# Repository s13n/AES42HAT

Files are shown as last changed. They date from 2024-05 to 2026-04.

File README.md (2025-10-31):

# AES42HAT

The AES42HAT is a Raspberry Pi compatible HAT with up to 4 channels of
AES3/AES42 interface. At present it is a work in progress.

AES3 is the stereo digital audio interface for professional applications, which
is compatible to some extent with SPDIF as used on consumer gear.

AES42 is building on AES3 to provide power and control for digital microphones.

Depending on what is fitted on the board, AES42HAT supports up to 4 stereo
channels of input/output, with or without SRC on input, and with or without
external synchronization.

Raspberry Pi models up to the Raspberry Pi 4B, and various clones, support only
one stereo channel in/out. The Raspberry Pi 5 supports the full set of 4 stereo
channels. The BeagleY-AI also supports 4 stereo channels in/out.

The 4 inputs and outputs are available on a header that supports the "Tascam
pinout" (or AES59 pinout) for a 25-pin SubD connector for multichannel digital
input/output. A standard IDC cable adapter between the header and the SubD
connector is needed.

## Build variants

The design supports different variants, depending on which parts are fitted on
the board. This allows a tradeoff between cost and feature set, depending on
user's needs.

See the schematics for the function blocks that can be omitted if desired. The
bare minimum consists of the parts that are shown outside of an optional block.

The Raspberry Pi uses the ID EEPROM to determine the build variant.

### Minimum build -- AES42HAT lite

The minimum build uses a DIX4192 for U10, and omits everything in the optional
blocks. It provides a stereo input/output in AES3 format, without SRC. It is
compatible with most Raspberry Pi models and some clones, provided they feature
a PCM interface on the standard pins, and a finely adjustable clock source on
GCLK0. It offers minimal cost for stereo applications that don't need AES42
support or SRC.

The lack of SRC means that there are only two sensible clocking options:

- The Raspberry Pi supplies the clock, and both input and output use it. This
  can be useful when an external device is connected, that synchronizes to the
  signal it receives from the AES42HAT.
- The output uses the clock derived from the received signal. This is useful
  when the external device is treated as the clock source, and the Raspberry is
  following it.

In both cases input and output use the same clock, i.e. they are synchronous to
each other.

The lack of a clock synthesizer means that the HAT is dependent on the Raspberry
Pi for a clock source. The original Raspberry Pi contains finely tunable PLLs
which can output a clock signal on GCLK0 that acts as a clock master. If a clone
doesn't support this, it won't work.

The lack of a control processor means that the DIX4192 is configured and
controlled directly by the Raspberry Pi through its SPI0 interface.

### Full-featured stereo interface -- AES42HAT stereo

This is the AES42HAT lite with an SRC4392 for U10, plus the clock synthesizer.

This adds the capability of using SRC on input, so the input clock can be
independent from the output clock. The presence of a clock synthesizer
eliminates the dependency on the Raspberry Pi clock generator, and adds a
separate wordclock input and output to support synchronization.

The clock syntheziser may also be slaved to a 10 MHz reference input as commonly
used in measurement equipment and frequency references. This can be used for
measurement purposes, or for creating audio clocks from GPS receivers and highly
stable oscillators.

The clock synthesizer is controlled by the Raspberry Pi through its I2C bus.

### Full-featured 8-channel interface -- AES42HAT octal

This adds 3 more stereo channels to the AES42HAT stereo to form a bidirectional
8-channel interface. SRC is supported on all channels by virtue of 3 more
SRC4392 chips, so that each input can run on its own clock, while all outputs
share a common clock generated by the local clock synthesizer.

The addition of more channels also requires the local control processor. The
SPI0 interface on the Raspberry Pi is no longer needed. All control is done via
the I2C bus, with the control processor managing the multiple channels.

Any of the input channels can be used as a synchronization source, instead of
the separate wordclock input.

The usage of a Raspberry 5 or a BeagleY-AI is needed to handle all the audio
channels.

### Full-featured 8-channel interface with AES42 support -- AES42HAT microphone

This adds AES42 compatible phantom power and remote control capability to all 4
stereo input channels of the AES42HAT octal. All synchronization modes of AES42
are supported, and the microphones can be remote controlled, independently for
each of the 4 inputs.

This requires a power supply that can deliver the necessary current for powering
the microphones in addition to the Raspberry Pi with the HAT. It is recommended
to use a 25W power supply capable of delivering 5A@5V to the Raspberry Pi 5.
Appropriate cooling should be provided.

The local control processor takes care of the AES42 specifics, and the Raspberry
Pi controls and monitors it via I2C.

If the goal is to merely power and control AES42 microphones, whose audio signal
is made available on the AES3 outputs, with no intent to process the audio with
the Raspberry Pi, then a cheaper/smaller Raspberry Pi can be used, for example a
Pi Zero 2. When intending to process the audio with the Raspberry Pi, use a
Raspberry Pi 5 or a BeagleY-AI.

## Function blocks

### Power Supply and Reset

The AES42HAT is powered through the HAT connector's 5V supply. Only the board ID
EEPROM (U3) is powered from the 3.3V supply on the HAT connector (J1). A dual
DC/DC converter (U4) generates local 3.3V and 1.8V rails for most of the
electronics on the board. The DC/DC converter is enabled by the 3.3V supply from
the HAT connector, so when the Raspberry Pi is powered down, the AES42HAT is
also powered down, even though the 5V rail may remain on.

The Raspberry Pi is responsible for lifting the RESET line after powerup,
otherwise the AES42HAT will remain in reset due to R5 pulling down the RESET
line. The ID EEPROM can be accessed regardless if the board is in reset or not.

### Local Control Processor (optional)

The 8-channel variants of the AES42HAT have a local control processor (U1)
fitted, which configures and controls the receivers and transmitters, and
handles the phantom powering, the remote control and the synchronization of the
AES42 interfaces.

The Raspberry Pi accesses the control processor primarily through I2C, using
pins 3&5 on the HAT connector. The Raspberry Pi controls this interface, and the
AES42HAT is the target. The communication protocol is TBD.

There is also a UART connection between the Raspberry Pi and the control
processor on pins 8&10. This connection can be used for updating the firmware of
the control processor from the Raspberry Pi. It may also be used during normal
operation for a console-like communication interface. The details are TBD.

There is an additional signal on Pin 26 of the HAT connector (REQ/ISP), which
serves two purposes:

- Upon release of RESET, the signal determines the boot mode of the control
  processor. When high, the control processor boots normally and executes its
  stored firmware. When low, it boots into a bootloader that can be used to
  update its firmware through the UART interface. Hence, to initiate firmware
  update, the Raspberry PI has to pull this signal low while releasing RESET.
- During normal operation, the signal is used as a service request signal from
  the AES42HAT to the Raspberry Pi. It is up to the Raspberry Pi to poll the
  signal, or arrange for an interrupt to be generated whenever the signal goes
  low. The control processor holds the interrupt active until the Raspberry Pi
  clears it through the I2C interface. The details are TBD.

When the control processor is fitted, the Raspberry Pi's own SPI interface on
HAT connector pins 19,21,23&24 is not used and must be disabled.

### Clock Synthesizer (optional)

The clock synthesizer supports generating arbitrary audio clock frequencies, and
to reference them to an external clock source. This provides considerable
flexibility in setting up the clocking structure of a system. The following
features are supported:

- Support for any sampling rate the Receivers/Transmitters are capable of (20 ..
  216 kHz). All transmitters use the same rate, and are synchronous to each
  other.
- Sampling rate can be finely tuned by software.
- An external 10 MHz reference can be connected to support synchronization from
  highly stable frequency sources (GPS receivers, OXCOs, Rubidium sources, ...).
  This can also help measurement applications. If no external reference is used,
  an internal 10 MHz crystal is used. The reference signal can be made available
  internally as the ACLK signal.
- Any one of the AES3 input signals can be used as the synchronization source.
- An external TTL wordclock signal can be connected to serve as a
  synchronization source.
- A TTL wordclock output is available.

All those features are controlled from software. The clock synthesizer is
connected to the I2C bus (HAT connector pins 3&5) that is controlled by the
Raspberry Pi. It produces two output clocks:

- The MCLK signal is the audio master clock from which the transmitters derive
  their output signal. The audio interface of the Raspberry Pi (PCM) is also
  driven from this clock, and operated in slave mode. The MCLK signal connects
  to pin 7 of the HAT interface. This allows the Raspberry Pi to supply the
  audio master clock instead of the clock synthesizer. The clock synthesizer's
  output must be switched off in this case (if it is fitted).
- The ACLK signal is typically driven by the 10 MHz reference clock signal. It
  can be used in the AES3 receivers as a reference signal for measuring incoming
  sampling rates.

The MCLK frequency should be between 10 and 25 MHz. For a single-speed sampling
rate up to a nominal 48 kHz, MCLK should be 512 * Fs. For a double-speed rate up
to 96 kHz it should be 256 * Fs. For a quad-speed rate up to 192 kHz it should
be 128 * Fs. The dividers in U10 must be set up to divide this down to the right
bit clock and word clock.

The clock synthesizer has a separate synchronization input that is driven by the
RCLK signal. Its use is optional, determined by software.

- If RCLK is not used, the 10 MHz signal is used as the reference, from which
  MCLK is derived directly using a fractional PLL.
- If RCLK is used, MCLK is derived from it by steering the fractional multiplier
  of the PLL to track the frequency of RCLK. This also reduces the jitter that
  may be present on RCLK. A wide frequency range on RCLK is supported (50 Hz ..
  30 MHz). Skipped pulses on RCLK can also be supported.

The RCLK signal can be fed from different sources:

- In the default case, it is fed from the external wordclock input. This is a
  TTL level signal that need not work at the wordclock frequency. It may be used
  to synchronize to a wide range of external frequency sources. The Raspberry Pi
  must enable it by driving the WIEN signal low.
- It can alternatively be fed from one of the receivers, using their RXCKO
  output. This output can be enabled to provide a clock signal derived from the
  incoming AES3 signal. It allows an incoming audio signal to be used as the
  synchronization source for the clock synthesizer. On 8-channel variants of
  AES42HAT, only one of four receiver chips can have this output enabled, or
  they will interfere with each other, potentially leading to damage. The output
  is disabled by default. Before enabling one of them, the Raspberry Pi must
  disable the external wordclock signal by driving the WIEN signal high.
- The Raspberry Pi can drive the RCLK signal using its GCLK2/GPIO6 signal on pin
  31 of the HAT connector. Both the wordclock input and the receiver RXCKO
  outputs must be disabled before the Raspberry Pi can activate this signal.

The clock syntheizer can be a CS2000 (obsolete), a CS2500 or a THAT7200. Its I²C
address is 0x4F (0x9E for write, 0x9F for read).

### AES Receivers/Transmitters

Decoding and encoding of the AES3 signal is done by U10 (on 8-channel variants
also U20, U30 and U40). There are three pin-compatible chips that can be fitted
alternatively:

- The **DIX4192** is a receiver and transmitter for one AES3 signal, including
  the balanced driver and receiver necessary for the physical interface.
- The **SRC4392** includes a sampling rate converter (SRC) that can be used with
  either the receiver or the transmitter, but is most useful with the receiver.
  Its other functions are the same as with the DIX4192, and the software
  interface is compatible.
- The **SRC4382** saves some cost by including a less accurate SRC that offers
  worse signal to noise. While this chip can be used, the cost savings are
  usually not worth it, and the AES42HAT will only use it upon special request.

Whichever chip is fitted, most of the functionality is the same. It has an
extensive register set for controlling the details of operation, which is
accessed through an SPI compatible interface.

When the local control processor is fitted, it is in control of the SPI
interface used to configure and control the receivers/transmitters.

The chips have flexible internal signal routing and clocking, which is set up
through the SPI control interface. Routing and clocking is set up as follows:

- U10 is the clock master on the PCM interface to the Raspberry Pi. Audio port A
  is configured in master mode and produces the BCLK and LR clock signals, with
  MCLK as the clock source. The BLS pin is configured as output.
- When fitted, U20, U30 & U40 operate their audio ports A&B in slave mode, so
  the BCKA, BCKB, LRCKA and LRCKB pins are inputs. The BLS pin is also
  configured as input.
- The transmitters within U10, U20, U30 and U40 are typically configured to be
  sourced from audio port A. The transmitter thereby sends an audio signal
  provided by the Raspberry Pi.
- Alternatively, the received input signal can be passed through to the output
  directly, using the pin multiplexers, bypassing the DIR and DIT blocks.
- The SRC is used with the receiver to convert the sampling rate of the received
  signal to the clock used on port A. If the input signal is known to be
  synchronous with this clock, the SRC can be omitted from the signal path.
- The ACLK signal (nominally 10 MHz) is available on the RXCKI signal, and can
  be used as a reference for the SRC to estimate the ratio. It can also be used
  as a reference clock for the DIR block. When the clock synthesizer is not
  fitted, the ACLK signal is not available, and the MCLK signal must be used as
  a reference.

Each receiver/transmitter has 4 GPO pins that have programmable functionality.
On the AES42HAT, they are used as follows:

- **GPO1** is used to enable phantom power for the AES42 input. If the AES42
  circuit is not fitted, the signal is unused. The output defaults to low after
  reset, thereby turning phantom power off.
- **GPO2** is used to select between two synchronization modes of AES42. This is
  only relevant when phantom power is switched on. A low signal selects mode 2,
  which is the default after reset.
- **GPO3** is connected to the control processor, and is intended to carry the
  reconstructed wordclock signal from the receiver ("Receiver Internal Sync
  Clock"). If the control processor is not fitted, the signal is unused.
- **GPO4** is connected to the control processor, and is intended to carry the
  received U-bit ("Receiver User Data Bit"), giving the control processor an
  alternate way to process the incoming user bit. If the control processor is
  not fitted, the signal is unused.

If the intended functionality of GPO3&4 is not required, other signals may be
chosen to be fed to the control processor.

Each receiver/transmitter can generate an interrupt signal. The interrupt signal
is handled by the control processor, if it is fitted. Otherwise the interrupt
from U10 is fed to the Raspberry Pi on HAT connector pin 26.

### AES42 Phantom Supply and Remote Control

AES42 defines a way of powering a connected microphone using a 10 V phantom
power scheme. Additionally, remote control signals can be sent to the microphone
by modulating them on top of the phantom power. The "AES42HAT microphone", the
fully featured variant, supports both.

Phantom power is generated by a DC/DC converter (U51, U61, U71, U81). Each input
can be powered separately, controlled by GPO1 of the respective
receiver/transmitter. The DC/DC converter works from the +5V rail, and each
circuit potentially draws up to 600mA from this rail, depending on the load
represented by the microphone that is connected. The power supply used must be
able to deliver this amount of current.

The control processor can monitor the phantom voltage through signals PVx, so it
can diagnose short circuits or overload.

Remote control using AES42 Mode 2 is handled by raising the phantom voltage for
each pulse generated. This is achieved by temporarily switching the DC/DC
converter to output 12 V instead of 10 V. Edge speed is shaped by an additional
driver (U52, U62, U72, U82).

Mode 3 is supported by a different circuit built from a signal transformer (L50,
L60, L70, L80) driven by a bandpass amplifier (U53, U63, U73, U83). It is based
on a clock signal WCLK generated by the control processor.

For both modes, the modulating signal (MODx) is generated by the control
processor. Switches (U50, U60, U70, U80) are used to select between the two
modes, depending on signals M3x sourced by GPO2 of the receiver/transmitter.

An LED shows the presence of phantom power on each channel. Its brightness is
modulated by the remote control pulses.

### Dependencies Between Optional Function Blocks

The control processor must be fitted if any of U20, U30 or U40 are fitted. It
must also be fitted when the AES42 circuitry is fitted.

The clock synthesizer is controlled by the Raspberry Pi and can be fitted
without the control processor. The clock synthesizer is independent from any
other function block and can be fitted or omitted, regardless of which other
options are fitted. However, if not fitted, the Raspberry Pi must supply the
audio master clock (GCLK0).

## Support for Raspberry Pi Variants and Clones

The AES42HAT is fully compatible with the Raspberry Pi 5, including support for
up to 8 channels of audio input and output.

Previous models of the Raspberry Pi up to the 4B only support stereo audio. The
8-channel variants of AES42HAT can therefore not be fully supported, i.e. the
audio signals of the additional channels can't be accessed by the Raspberry Pi.
The additional channels can be controlled and configured, however, so it is
possible to support use cases where the audio signals need not be touched by the
Raspberry Pi (for example using pass-through from input to output, without or
with SRC).

Raspberry Pi clones may or may not support the PCM interface, so it is up to the
user to check compatibility. In many cases only stereo is supported, if at all.

### BeagleY-AI

The BeagleY-AI is a clone that can support all 8 channels, albeit with some
special arrangements. The pin assignment for the PCM interface is only partly
compatible with the Raspberry Pi 5, and AES42HAT contains some additional wiring
to make up for the difference.

With the BeagleY-AI, the McASP0 is used for all the input signals with up to 8
channels. The output channels are generated by McASP1 and McASP2 in SPDIF
transmit mode. The latter is necessary because of limitations of clock signal
connectivity. The input multiplexers in the receivers/transmitters are used to
route the output signals directly to the balanced line driver, bypassing the DIT
block. To deal with wiring differences for input channels, audio port B is used
on U30 and U40.

### ESP32-P4 Function Evaluation Board

The Espressif ESP32-P4 is a microcontroller with a dual-core RISC-V CPU and a
rich set of peripherals, including I2S and 100 MBit/s Ethernet. It appears to
have some potential for a very low cost platform for low-end networked audio
devices, below the price point of a Linux-based solution. Its evaluation board
has a set of GPIO signals routed to a Raspberry Pi HAT connector. This opens the
possibility to use the AES42HAT as an audio interface.

The ESP32-P4 has 3 I2S function blocks that can be freely assigned to GPIO pins,
and it includes a PLL dedicated for audio. It therefore should be able to work
with the AES42HAT directly, with no need for a wiring change. At the time of
writing, the information available for the ESP32-P4 is sparse, hence the
suitability is somewhat unclear at this point, but it certainly looks promising.

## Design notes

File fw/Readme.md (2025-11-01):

# AES42HAT firmware

The AES42HAT uses the LPC865M201 as a local control processor (U1). The firmware
for this MCU is contained in this folder here.

The control processor has a number of responsibilities on the AES42HAT:

- Initialize the board
- Collect the user bit and control/status bit data from the AES Receivers (U10,
  U20, U30, U40) via SPI, and present them to the Host processor via I2C.
- Receive the user bit and control/status bit data for the AES Transmitters (U10,
  U20, U30, U40) from the host via I2C, and set them via SPI.
- Measure the relative clock phases between the AES Transmitters, and each of
  the AES Receivers, to support AES42 Mode 2 synchronization.
- Manage phantom powering and remote control of an AES42 compatible source.

The details are described in the succeeding chapters here.

## General control processor operation

The control processor is mainly used for configuring the transceiver chips, and
for handling the channel status and user bits of the AES3 / AES42 signals. This
is important since AES42 makes full use of those bits, and it greatly helps a
host processor when this side-band information handling is offloaded into a
specialized processor.

### Handling of C and U bits

The transceiver chips U10, U20, U30 and U40 have a double-buffered memory for
the entire C and U bit information for both receiver and transmitter side. The
buffers can be accessed through the SPI control port. The speed of the SPI port
is sufficient for keeping up with the data rate of 4 transceivers operating in
parallel in both directions (using the I2C bus mode instead wouldn't provide
enough speed). The control processor is intended to read the incoming data on
all channels once for every block of 192 samples. Optionally, it should also be
able to write the outgoing data for all 4 channels for every block of 192
samples, too.

The transmitters are all synchronized to the same clock, therefore the data
blocks can be written in common. The trigger (interrupt) for writing new blocks
comes from the BLS signal. For each trigger, 192 * 8 * 2 bits = 3072 bits = 384
bytes must be written if all channels are to be covered. This is because there
are separate blocks of 192 bits for each of 8 subchannels' C and U bits.

The receivers are clocked individually, and each may operate at a different
frequency. Therefore the data transfer is triggered separately for each. With
each trigger, 768 bits = 96 bytes must be read. The trigger comes from the INT
signal of the respective transceiver, which must be programmed to fire once per
received block.

This means that 5 independent trigger sources compete for SPI bandwidth,
requiring arbitration. The worst case occurs at the highest sampling rates of
~200 kHz for both receivers and transmitters, which leads to a total net data
rate of 800 kByte/s, or 6.4 MBit/s. In practice, the clock rate of the SPI port
will therefore need to be 10 .. 30 MBit/s, which is within the capability of
both the control processor and the transceiver chips.

The SPI interface in the control processor supports DMA, which is useful in this
scenario, to relieve the CPU of handling the actual data transfer.

Note that all 5 trigger signals (BLS, INTA, INTB, INTC, INTD) are connected to
support time stamping with FTM0. This permits phase measurements (see below), as
well as frequency measurements. FTM0 has 6 channels, of which 5 are used for
this purpose.

### Transceiver configuration

The control processor configures the transceiver chips according to the desired
operation mode. This is determined by the host processor, which uses the I2C
interface to set the operation mode by writing control data to the control
processor. The control processor then configures the transceivers accordingly
via SPI0.

### Other functions

The control processor monitors the phantom voltage of all 4 channels using its
ADC (inputs ADC_0 .. ADC_3). It can report the values to the host via the I2C
interface. A significant deviation from the nominal values of 10V or 12V
indicates a hardware problem.

Host communication, microphone synchronization and remote control are described
below in their respective chapters.

### Control processor clock setup

Most of the functions of the control processor don't need to be synchronized
with the audio clock. An internal free running oscillator can clock the chip at
60 MHz, and generate most of the required clocks, including the CPU clock.

For additional flexibility, both MCLK and ACLK signals are routed to the control
processor where they can be used for further clocking related tasks. Either one
or the other can be used to supply the internal `external_clk` signal, which can
serve as the reference for a PLL to generate arbitrary frequencies.

## Mode 2 clock synchronization

When AES42 was developed, one of the problems to solve was how to synchronize
the microphone to a common wordclock, given that the audio signal runs in the
"wrong" direction from the microphone to the controller, where the synchronizing
wordclock needs to go the other way. The solution devised was to establish a
distributed PLL using the remote control facility, which allows low-speed
control signals to be sent by the controller to the microphone via a modulation
scheme of the phantom power. A periodic control word generated by the controller
transmits the phase error to the microphone, where it tunes the clock generator
to produce the correct frequency.

The modulation scheme requires the phantom power of nominally 10 V to be raised
to 12 V in pulses that contain the information. On the AES42HAT, this is done by
switching a boost switchmode regulator between 10 and 12 V, and shaping the
transitions with a pulse driver. This avoids the power dissipation losses of a
linear regulator that is commonly used for this function.

### Controlling pulse timing

The pulse timing is controlled by the control processor, taking advantage of its
FTM1 timer module in conjunction with firmware. In mode 2, the pulses needn't be
synchronous with the wordclock, so the only requirement is to produce the
correct pulse widths according to the AES42 specification. This allows the TIM1
to be clocked internally. FTM1 has 4 channels which are used to control the 4
AES42 channels, so communication can proceed on all channels simultaneously.
Each of the timer channels controls one MODx signal.

The basic idea is to program the TIM1 such that its counter produces one TOF
event per bit that is sent as the remote control signal. Each bit is represented
by a signal that is initially low, and changes to high during the bit period.
For a 0 bit the transition to high happens late during the bit period, while for
a 1 bit it happens early.  This can be generated by using the PWM capability of
the TIM1. During the bit period the counter counts up from its initial value in
CNTIN to its final value in MOD, thereby defining the time for an entire bit.
Somewhere in between, an output transition happens as a consequence of a compare
event. This is what is described as "Edge-Aligned PWM" in the reference manual
of the control processor.

It is possible to trigger a DMA channel on the reloading of the counter (see bit
INITTRIGEN), and have it rewrite the compare registers. This can be used to
reduce the interrupt load by precomputing a list of transition points and
placing it in memory. Alternatively, an interrupt can be generated and the
interrupt service routine takes care of setting the compare registers once for
each bit period.

Firmware bears the responsibility to convert the data to be sent into the
appropriate timing values to use by the TIM1 channel for each bit.

### Phase detection

The control processor implements the phase detection part of the distributed
PLL. It consists of comparing the phase of the incoming AES42 signal with the
local wordclock signal. One phase measurement is needed for each time a control
word is sent to the microphone, which is nominally 6 times per second. Therefore
it is acceptable, and even advantageous, to use the block start signal instead
of the wordclock, to take a phase measurement. This allows aligning the block
start in addition to the wordclock.

The action of the PLL is supposed to minimize the phase error by steering the
clock generator in the microphone. To achieve this, the measured phase error is
filtered and converted into a 13-bit data word which is sent to the microphone 6
times per second. The microphone uses the data word to set the frequency of the
clock generator within a narrow band centered around the nominal frequency.
Traditionally this was done by having a D/A converter control a voltage
controlled crystal oscillator. Other arrangements that produce a similar effect
are also possible, however.

The phase detection is done with the help of TIM0 in capture mode. Its channel 3
captures the edges of the BLS signal, which is the block start signal derived
from the local wordclock. This serves as the reference against which the phase
of the incoming signal from the microphones is measured. The 4 AES42 inputs use
channels 0, 1, 4 and 5 of TIM0, so their phases can be measured simultaneously.
The phase difference is the capture value of the microphone channel minus the
capture value of the reference channel.

The counter of TIM0 is free running, and clocked internally from a clock source
that is unrelated to the audio clocks. This effectively dithers the measurement
results and avoids systematic quantization errors. Additionally, since block
starts are much more frequent than control word transmissions, measurements can
be averaged or smoothed to increase resolution even further.

Implementing phase detection in this way depends on each transceiver chip (U10,
U20, U30, U40) generating an interrupt signal when there is a block start of the
incoming audio signal. This also signals that a complete block of channel status
and user bits has been received and should be fetched using the SPI interface,
so the interrupt signal should not merely cause a capture in TIM0, but the
interrupt service routine should also schedule the data transfer using the SPI
interface.

### Fast mode

The AES42 standard supports two different communication speeds for the remote
control signal, standard mode and fast mode, with support for the latter being
optional for both the microphone and the controller. The implementation
described above for the AES42HAT can support either, but all four channels must
operate in the same mode, because of the usage of a common timer for generating
the timing.

In practice, fast mode would therefore be useable only if all connected
microphones support it. It shouldn't be selected otherwise.

## Mode 3 clock synchronization

As mode 2 synchronization has some disadvantages, Schoeps devised an additional
mode 3 as a different way of remote controlling and synchronizing the
microphone. In mode 3, the synchronization doesn't use the remote control
facility, it is the other way around. The remote control commands get sent
using the synchronization signal as a carrier.

Synchronization is achieved by modulating a low level sinewave onto the phantom
power, with the wordclock frequency as the carrier frequency. On the microphone
side, a narrow band circuit can retrieve this carrier despite its low level. The
advantage is that the chance of interference with the audio signal in the
microphone is greatly reduced, as is the potential radiation from the cable.
Furthermore, it is not necessary to support remote control just for
synchronization. If synchronization is all that's needed, it suffices to just
send the carrier.

The controller needs to be able to generate a sinewave to be superimposed on the
phantom power, and the phase of this sinewave should be directly related to the
local wordclock. This is achieved by bandpass filtering the WCLK signal to
remove harmonics and approximate a sine wave.

The WCLK signal is always at the base frequency, even for double or quadruple
sampling rates, so in practice it is at 44.1 or 48 kHz. This means that there
must be a separate divider to generate it. This can be implemented with the help
of the PLL and the CLKOUT divider, but the SPI1 could also be employed in a
creative way to achieve this.

The remote control signal must be synchronous to the carrier, as each bit that
is sent modulates the amplitude of one full sine wave period. This is achieved
by clocking UART2 with the wordclock signal and using the UART transmit signal
as the modulating signal. Only one microphone can be talked to at any one time
in this way, but since synchronization in mode 3 does not depend on remote
control communication, this isn't a serious drawback.

## Console mode

As an extension to AES42, Schoeps has defined a console mode that uses the user
bit of the right subchannel for a console channel that transmits arbitrary data
in UART format for supporting a textual console connection with the microphone
that can be used during normal operation. Together with an extension of the
remote control command set, this allows bidirectional communication with the
microphone for arbitrary purposes, including an extended command set that
supports functionality beyond what AES42 provides.

Standard AES42 assumes that the user bit of both subchannels contains the same
data, and typically a controller receiving the signal would only look at the
left subchannel. Using the right subchannel therefore doesn't usually impair
normal operation, and the full information AES42 sends in the user bit is still
available.

Console mode is not normally necessary with multiple microphones concurrently.
Therefore the AES42HAT supports using console mode with one microphone at a
time. Multiple microphones can be in console mode concurrently, but only one can
send data at a time, as the AES42HAT can only communicate with one of them.

Towards the host processor, i.e. the Raspberry Pi, the console data is forwarded
from/to its UART interface on Hat pins 8&10, using UART0 of the control
processor. The I2C interface is used to select the microphone to communicate
with.

To support console mode, channel status and user bits must be treated separately
for each of the two subchannels. The AES42HAT is capable of doing this. Incoming
console data in the user bit of the right subchannel can be treated in two
different ways:

### Console mode through SPI0

Here, the data for both user bits and channel status bist for both subchannels
is read by the control processor via SPI0 once for each channel status block
(i.e. once every 192 samples). This is usually done anyway, hence no additional
communication is needed.

The data is decoded in software using the CPU, hence this method causes a
significant CPU load. The problem is mainly to find start bits, which can occur
anywhere in the U-bit stream, and extract the following 8 bits as a data byte.
This bit banging is CPU intensive.

### Console mode through UART1

By using GPO3 and GPO4 of each transceiver chip for the receiver wordclock and
the U-bit, respectively, a situation is created where UART1 can be directly used
to receive the signal in synchronous mode. This saves considerable CPU power by
using the UART hardware intelligently.

## Host communication

The host processor controls the operation of the AES42HAT, i.e. its control
processor, via I2C on pins 3&5 of the Hat connector. The control processor is
the target, and the host processor is the controller. This makes the AES42HAT
appear to the Host processor as a peripheral in much the same way as an audio
codec would be. Configuration is done by writing to registers, and status is
monitored via reading of registers, using the I2C protocol in the usual way.

When the AES42HAT requests the attention of the host processor, it pulls the
REQ/ISP signal low until the host processor services the request. The host
processor would typically react by reading a service request status word via
I2C, which allows it to identify the nature of the request, and service it
accordingly.

The UART interface between host and control processor on pins 8&10 of the Hat
connector is used for remote control of the microphone, and for console mode. It
can also be used for updating the control processor firmware.

### I2C communication

The I2C target of the control processor reacts to a range of I2C 7-bit addresses
like detailed in the following table:

| Addr | Function |
|---|---|
| 0x70 | U10 passthrough |
| 0x71 | U20 passthrough |
| 0x72 | U30 passthrough |
| 0x73 | U40 passthrough |
| 0x74 | board control |
| 0x75 | service request status |
| 0x76 | Remote command buffer |

The passthrough mode allows the host to access the transceiver chips as if they
were connected directly to the I2C bus. This is intended to help driver software
that was written for a direct connection of the SRC4392 to the I2C bus. The
target addresses are chosen to be compatible with the I2C mode of the SRC4392.
The control processor arbitrates between its own accesses to the transceiver
chips, and those by the host processor.

### UART communication

The UART interface is used for microphone remote control and console mode. One
of the microphones is selected via I2C as the peer to communicate with. When no
microphone is selected, the UART interface can be used as a console interface
with the control processor, if desired.

A baud rate of 230400 bits/s is used with no parity and 1 stop bit. This is
faster than the microphone side, so the possibility exists that the host
overruns the buffering of the AES42HAT, which is handled by XON/XOFF signaling
by the control processor to the host. There is no need for that in the other
direction, as the host should always be quick enough to receive data.

The control processor translates data it receives from the host processor into
remote control pulses for the microphone, according to the selected remote
control and synchronization mode. It can buffer an entire line of at least 80
characters before overrunning.

The control processor forwards console data it receives from the microphone to
the host processor.

## Control processor pin functions

The LPC865 has great flexibility in assigning peripheral functions to pins. We
try to make the best use of this in order to allow some different options for
firmware to take advantage of. However, some functions assignments are
predefined by the chip's architecture, and those restrict the overall pin
function assignments. Other pin assignments not described here are completely
flexible through the switch matrix.

The pin assignments are done such that a 2-channel hardware design can easily be
derived as a spinoff design, with the 32-pin package of the LPC865 being
sufficient. This means that pins `PIO0_29` and onwards are used for channels C
and D only.

Here's the rationale behind the pin assignment:

### Reset, boot and firmware update

The controller runs from an internal boot ROM after reset, and depending on the
state of the `PIO0_12` pin it starts the user program in flash, or it waits for
a firmware image to be provided to UART0 for in-system programming of the flash.
Pulling the pin high, or leaving it getting pulled up by a resistor, results in
the user program to be invoked, which is the normal operating case. Pulling it
low upon reset invokes the ISP handler that sets up UART0 on `PIO0_24` and
`PIO0_25` for receiving commands from the host computer, using the UART ISP
protocol described in the user manual of the LPC865.

Of course, this requires external control of the reset pin `PIO0_5`. This fixes
the function of the four pins mentioned.

### Clocking

Besides the crystal oscillator on `PIO0_8` and `PIO0_9`, the `CLKIN` function is
also fixed to a single pin, `PIO0_1`. So we use the pins for those functions.

We only need the `XTALIN` function, leaving the `XTALOUT` function free, but we
play it safe and use the latter only as a test point.

The `ACLK` signal on `CLKIN` comes from the clock synthesizer chip, which allows
some flexibility regarding what's fed to the `ACLK` signal. It can be the 10 MHz
reference, or the `RCLK` signal that's routed through, or even the PLL lock
status. Note that it is the host processor that has control over the clock
synthesizer chip, so the controller works with whatever is being presented to
it.

### Debug

Two signals are required for SWD debugging, using pins `PIO0_2` and `PIO0_3`.
They are 3.3V logic compliant, so if you are using a debug probe that needs a
sense voltage to determine the logic levels it should use, like many probes by
Segger, you need to provide a 3.3V voltage.

The debug probe doesn't control the RESET signal. The SWD debug port of the
LPC865 is disabled while the chip is in reset. If debugging is to work, the
Raspberry PI first needs to release the RESET signal connected to its `GPIO12`.
One of the ways to do this is via the `gpioset` utility, as is done in
`release-reset.sh`. Note that `gpioset` keeps the GPIO signal in the selected
state until the process is terminated.

One further pitfall to consider is the CRP (Code Read Protection) of the LPC865.
It relies on a particular bit pattern in location 0x02FC in Flash, which is in
the first Flash sector. To avoid trouble, the simplest measure is to make sure
that user code, except the vector table, starts in sector two, and the free
space in sector one is filled with 0xFF. If this isn't heeded, programming the
Flash may fail.

Of course, the space in the first sector, after the vector table, could be used
for some purpose, for example secondary bootloader, provided that the crucial 4
bytes at 0x02FC are spared, and left at 0xFFFFFFFF.

### I2C communication

Two pins, `PIO_10` and `PIO_11`, are specially equipped for I2C usage in their
driving capability, so we use them for that purpose.

The I2C bus is used in target mode, for the Raspberry PI in the controller role.

### UART communication with the host

We already have assigned UART0 on pins `PIO0_24` and `PIO0_25` for firmware
download, so we keep that for host communication.

### Analog input

The four analog signals `PVA` .. `PVD` need to be connected to one of the inputs
of the controller's ADC. It makes most sense to use `ADC_0` .. `ADC_3`, and thus
pins `PIO0_7`, `PIO0_6`, `PIO0_14` and `PIO0_23`.

The ADC measurement is based on the external reference on pins `VDDA` and
`VSSA`, whose accuracy depends on the switchmode regulator, i.e. it is not very
accurate. It is only suitable for determining whether the phantom voltages are
approximately within the desired range. This is adequate for diagnosing faults.

### FTM0 operation

Pin connectivity of FTM0 is somewhat limited, with only 2 or 3 choices for each
function. We try to allow as much flexibility as possible for firmware to use
FTM0 in controlling the clocking and making phase measurements.

Five of the six available timer channels are needed to measure the wordclock
phases of the 4 inputs against the output wordclock. This is needed for the
implementation of mode 2 synchronization of AES42 sources, but can also be used
in other modes for phase measurements. This functionality is based on the block
synchronization signals that occur once every 192 sample periods. It uses the
input capture mode of the timer channels.

There are two different methods that can be employed for this emasurement. The
synchronous mode and the asynchronous mode. The distinction is whether the
counter is clocked with a clock source that is synchronous with the phase
reference, or whether the clock is independent and asynchrous. There is
something to be said in favor of the asynchronous mode, because the
asynchronicity provides a form of dithering that can help avoiding systematic
effects due to quantization on the time axis. But either mode should be usable
for the task.

The synchronous mode requires the counter to be clocked by a source that is
associated with the local wordclock, i.e. it must ultimately be derived from
`MCLK`. There are two alternatives for arranging this:

- The `MCLK` signal can be used as the "external_clk" signal that can be used
  either directly as the main_clk, or as the reference for the Main PLL inside
  the controller. Either way the resulting clock for the FTM0 will be shared
  with the CPU, which makes the CPU run synchronously with the audio clock, too.
  This may or may not be what is desired for the firmware. Furthermore, it makes
  the `ACLK` signal almost unusable, because it can't feed the "external_clk"
  signal.
- The `BCK` signal can be used to clock the FTM0 counter through `PIO0_30`.
  This is the bit clock at 64* the wordclock frequency. It supports phase
  measurements with the resolution of one bit position in the serial data
  stream. Note that this is not supported with the 32-pin package.

The asynchronous mode clocks the FTM0 counter from an internal clock source,
most likely the FRO, which would also clock the CPU. The asynchronicity will add
a randomness to the sampling point with respect to the wordclock, so that
greater accuracy can be achieved by averaging successive measurements. The PLL
action inherent in the AES42 mode 2 does this anyway.

The block synchronization signal for the transmitting side is `BLS`, which is
generated by channel A and used by the other channels to align their transmitter
phase. It is obtained in U10 by dividing down MCLK. It serves as the reference
against which the phase of the 4 input channels can be measured.

The block synchronization signals for the 4 receivers are independent. Each
channels has two alternatives:

- The `INTx` signal, which must be programmed in each transceiver chip to
  produce an impulse for each received block start. (preferred)
- The `GPO3` output of each transceiver, i.e. the `UCKx` signals. This pin must
  be programmed to produce a pulse for each received block ("Receiver Block
  Start Clock"). This precludes using the pin to clock a UART for doing console
  mode with the help of a UART, i.e. console mode support must be implemented in
  firmware only. On the positive side, the `INTx` signal is free for other use.

The controller is wired up to support either of those alternatives, given the
pin assignment restrictions for FTM0. The `BLS` signal uses `PIO0_17` of timer
channel 0. The four transceivers' interrupt outputs `INTx` use timer channels
2..5 on pins `PIO0_19`, `PIO0_20`, `PIO1_5` and `PIO1_6`. Alternatively, the
`UCKx` signals can be used on pins `PIO0_22`, `PIO0_21`, `PIO1_4` and `PIO1_3`.

Channel 1 of FTM0 can be used in conjunction with the generation of the
`WCLK` signal, which is described in a later section.

### FTM1 operation

Pin connectivity of FTM1 only supports two pin alternatives for each function,
so pin assignments must try to make good use of that. To make matters worse,
some alternatives overlap with FTM0. We try to support the role of FTM1 in
generating the remote control modulation signals in AES42 mode 2 as flexibly as
possible.

The 4 modulation signals are controlled by one of the FTM1 channels each, thus
making full use of the FTM1 capabilities.

The remote control pulses used in mode 2 may or may not be synchronized with the
wordclock. AES42 is not specific about that, however the pulse timing is
described with reference to the "basic sampling frequencies". This suggests that
it would be prudent to be able to synchronize the pulses to the wordclock signal
`WCLK`. Clocking the FTM1 counter from `WCLK` achieves this, which happens
through `PIO0_29`. Again, this is not supported with the 32-pin package.

Alternatively, the counter can be clocked from an internal, asynchronous clock
signal, which results in the remote control pulses running asynchronously from
the wordclock.

The counter channels are operated in output compare mode, with each `MODx` pin
being controlled by one of the FTM1 channels. The pins are assigned accordingly,
to `PIO0_15`, `PIO0_16`, `PIO0_31` and `PIO0_1`.

Note that the `UBTx` signals, which come from the transceivers, use the FTM1
alternative pin assignments `PIO0_27`, `PIO0_26`, `PIO1_9` and `PIO1_8`. This
can be used to support other kinds of measurement functions in conjunction with
whatever signals can be routed to the `GPO4` transceiver outputs.

### WCLK generation

The `WCLK` signal must operate at the basic sampling frequency, hence it can't
be the same as the `LR` signal that can also be at double or quadruple this
frequency, depending on the sampling rate chosen for the transmit side. It is
also desirable for the `WCLK` signal to be controllable in phase. Unfortunately,
no hardware is available inside the controller that fulfills all those demands
directly and simply. There are workarounds, however.

A relatively simple way is to use the `CLKOUT` function on `PIO0_29`, which
requires the Main PLL to be employed. It is not easy to control the phase of the
signal with this method, however.

Better flexibility, including control of the phase, is achievable by employing
SPI1. It works like this:

- Operate SPI1 in slave mode, with the clock coming from `BCK` on pin `PIO0_30`.
- Keep the slave selected continuously, so that a steady data stream results.
- Use the MISO1 output as the `WCLK` signal on `PIO0_29`.
- Use a DMA channel to read cyclically from a pattern buffer in memory.

This permits the SPI1 to output a freely definable serial pattern to be used as
the `WCLK` signal. The firmware controls its shape, including its phase, by
setting the content of the circular buffer, with a resolution defined by the bit
clock.

To measure the phase of the signal, it is possible to employ the help of FTM0
and FTM1 in the following way:

- Clock FTM1 from the `WCLK` signal via `PIO0_29`.
- Program a PWM on `PIO0_16` using FTM1 channel 1.
- Measure it using FTM0 channel 1, taking advantage of the shared pin `PIO0_16`.

This can be done once during startup, as the phase would be stable as a result
of setting up the dividers correctly. The timer ressources can be used for their
normal functions thereafter.

## I2C register maps

### Addresses 0x70 .. 0x73 (SRC4392 passthrough)

### Address 0x74 (Board control)

Board control functions are serviced by the control processor, independently of
the SRC4392 chips. The host processor will normally only need to access this,
and leave SRC4392 handling to the control processor.

| Addr | Register description  |
|---| --- |
| 0x00 | Reset, Initialization |
| .... | .... |
| 0x7F | Firmware Version |

### Address 0x75 (Service request status)

This address needs no register address to be sent. The service request status is
a bitmap that has a bit for each potential service request. As long as there are
unmasked bits set to one in this status word, the REQ signal to the host
processor will be active. The mask is located in the board control register set.
Bits in the service request status remain set until the function they're
representing is serviced.

Simple read transfers are used to read the service request word, which contains
bits to indicate particular service requests, like follows:

TBC

### Address 0x76 (Remote command buffer)

Each channel has a buffer of 64 bytes where commands are stored that are to be
sent to the microphone via AES42 remote commands. The host can select if the
buffer content should be sent once, or repeatedly.

Each command occupies 3 bytes, including the gap between successive commands. In
mode 3, the buffer isn't used, as the remote commands are issued via the UART
connection. When mode 2 is active, the controller inserts Direct Command 3 in
the sequence automatically, to maintain synchronization. The commands in the
buffer are issued in between.

Selecting repeated transmission allows microphone settings to be sent
repeatedly, so that commands issued to the microphone in a different way (e.g.
acoustically) are overridden. If that isn't desired, don't select repeated
transmission.

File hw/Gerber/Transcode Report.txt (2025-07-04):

   ---- Transcoding 'C:\workdir\Projekte\KiCad\AES42HAT\Gerber\AES42HAT-Edge_Cuts.gm1' ----   Mon Apr  7 13:58:13 2025

D10   --> D100
-----------------------------------------------------------------

   ---- Transcoding 'C:\workdir\Projekte\KiCad\AES42HAT\Gerber\AES42HAT-F_Cu.gtl' ----   Mon Apr  7 13:58:13 2025

D10   --> D101
D11   --> D102
D12   --> D103
D13   --> D104
D14   --> D105
D15   --> D106
D16   --> D107
D17   --> D108
D18   --> D109
D19   --> D110
-----------------------------------------------------------------

   ---- Transcoding 'C:\workdir\Projekte\KiCad\AES42HAT\Gerber\AES42HAT-F_Fab.gbr' ----   Mon Apr  7 13:58:13 2025

D10   --> D111
D11   --> D112
D12   --> D113
D13   --> D114
D14   --> D115
D15   --> D116
D16   --> D117
D17   --> D118
D18   --> D119
-----------------------------------------------------------------

   ---- Transcoding 'C:\workdir\Projekte\KiCad\AES42HAT\Gerber\AES42HAT-F_Paste.gtp' ----   Mon Apr  7 13:58:13 2025

D10   --> D120
D11   --> D121
D12   --> D122
D13   --> D123
D14   --> D124
D15   --> D125
D16   --> D126
D17   --> D127
D18   --> D128
D19   --> D129
D20   --> D130
D21   --> D131
D22   --> D132
D23   --> D133
D24   --> D134
D25   --> D135
D26   --> D136
D27   --> D137
D28   --> D138
D29   --> D139
D30   --> D140
D31   --> D141
D32   --> D142
D33   --> D143
D34   --> D144
D35   --> D145
D36   --> D146
D37   --> D147
D38   --> D148
D39   --> D149
D40   --> D150
D41   --> D151
D42   --> D152
D43   --> D153
D44   --> D154
D45   --> D155
D46   --> D156
D47   --> D157
D48   --> D158
D49   --> D159
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
-----------------------------------------------------------------

   ---- Transcoding 'C:\workdir\Projekte\KiCad\AES42HAT\Gerber\AES42HAT-F_Silkscreen.gto' ----   Mon Apr  7 13:58:13 2025

D10   --> D169
D11   --> D170
D12   --> D171
D13   --> D172
D14   --> D173
-----------------------------------------------------------------

   ---- Transcoding 'C:\workdir\Projekte\KiCad\AES42HAT\Gerber\AES42HAT-In2_Cu.g2' ----   Mon Apr  7 13:58:13 2025

D16   --> D174
D17   --> D175
-----------------------------------------------------------------

   ---- Transcoding 'C:\workdir\Projekte\KiCad\AES42HAT\Gerber\AES42HAT-In3_Cu.g3' ----   Mon Apr  7 13:58:13 2025

D16   --> D176
D17   --> D177
-----------------------------------------------------------------

   ---- Transcoding 'C:\workdir\Projekte\KiCad\AES42HAT\Gerber\AES42HAT-PTH.drl' ----   Mon Apr  7 13:58:43 2025

T1   --> T2
T2   --> T3
T3   --> T4
-----------------------------------------------------------------

   ---- Transcoding 'C:\workdir\Projekte\KiCad\AES42HAT\Gerber\AES42HAT-Edge_Cuts.gm1' ----   Mon Apr  7 15:37:45 2025

D10   --> D100
-----------------------------------------------------------------

   ---- Transcoding 'C:\workdir\Projekte\KiCad\AES42HAT\Gerber\AES42HAT-F_Cu.gtl' ----   Mon Apr  7 15:37:45 2025

D10   --> D101
D11   --> D102
D12   --> D103
D13   --> D104
D14   --> D105
D15   --> D106
D16   --> D107
D17   --> D108
D18   --> D109
D19   --> D110
-----------------------------------------------------------------

   ---- Transcoding 'C:\workdir\Projekte\KiCad\AES42HAT\Gerber\AES42HAT-F_Fab.gbr' ----   Mon Apr  7 15:37:45 2025

D10   --> D111
D11   --> D112
D12   --> D113
D13   --> D114
D14   --> D115
D15   --> D116
D16   --> D117
D17   --> D118
D18   --> D119
-----------------------------------------------------------------

   ---- Transcoding 'C:\workdir\Projekte\KiCad\AES42HAT\Gerber\AES42HAT-F_Paste.gtp' ----   Mon Apr  7 15:37:45 2025

D10   --> D120
D11   --> D121
D12   --> D122
D13   --> D123
D14   --> D124
D15   --> D125
D16   --> D126
D17   --> D127
D18   --> D128
D19   --> D129
D20   --> D130
D21   --> D131
D22   --> D132
D23   --> D133
D24   --> D134
D25   --> D135
D26   --> D136
D27   --> D137
D28   --> D138
D29   --> D139
D30   --> D140
D31   --> D141
D32   --> D142
D33   --> D143
D34   --> D144
D35   --> D145
D36   --> D146
D37   --> D147
D38   --> D148
D39   --> D149
D40   --> D150
D41   --> D151
D42   --> D152
D43   --> D153
D44   --> D154
D45   --> D155
D46   --> D156
D47   --> D157
D48   --> D158
D49   --> D159
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
-----------------------------------------------------------------

   ---- Transcoding 'C:\workdir\Projekte\KiCad\AES42HAT\Gerber\AES42HAT-F_Silkscreen.gto' ----   Mon Apr  7 15:37:45 2025

D10   --> D169
D11   --> D170
D12   --> D171
D13   --> D172
D14   --> D173
-----------------------------------------------------------------

   ---- Transcoding 'C:\workdir\Projekte\KiCad\AES42HAT\Gerber\AES42HAT-In3_Cu.g3' ----   Mon Apr  7 15:37:46 2025

D16   --> D174
D17   --> D175
-----------------------------------------------------------------

   ---- Transcoding 'C:\workdir\Projekte\KiCad\AES42HAT\Gerber\AES42HAT-PTH.drl' ----   Mon Apr  7 15:37:46 2025

T1   --> T2
T2   --> T3
T3   --> T4
-----------------------------------------------------------------

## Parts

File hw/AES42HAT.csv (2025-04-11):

ID | Bezeichner | Footprint | Stückzahl | Bezeichnung | Anbieter und Referenz
1 | R89,R59,R79,R69 | R_0402_1005Metric | 4 | 15k
2 | T3,T2,T5,T8,T6,T1,T4,T7 | Transformer_Wuerth_74930030 | 8 | 74930030
3 | R92,R4,R2,R44,R14,R90,R1,R24,R5,R34 | R_0402_1005Metric | 10 | 3k9
4 | C31,C11,C41,C21 | C_0402_1005Metric | 4 | 0µ1
5 | R51,R71,R81,R61 | R_0402_1005Metric | 4 | 59k
6 | L3 | L_Wuerth_MAPI-2512 | 1 | 4µ7
7 | R54,R74,R64,R84 | R_0402_1005Metric | 4 | 2k2
8 | TP6 | TestPoint_Pad_D1.0mm | 1 | RDYB
9 | R91,R12,R42,R22,R32 | R_0402_1005Metric | 5 | 470R
10 | C22,C25,C24,C44,C46,C97,C23,C14,C12,C13,C16,C40,C34,C96,C32,C36,C43,C42,C26,C20,C95,C10,C35,C30,C15,C33,C45 | C_0402_1005Metric | 27 | 100n
11 | D53,D63,D83,D73 | D_0402_1005Metric | 4 | BZX884B5V1L
12 | C59,C92,C89,C91,C79,C69 | C_0402_1005Metric | 6 | 10p
13 | R41,R70,R21,R80,R31,R60,R11,R50 | R_0402_1005Metric | 8 | 100R
14 | J2 | IDC-Header_2x13_P2.54mm_Vertical | 1 | Conn_02x13_Odd_Even
15 | C71,C2,C61,C1,C51,C81 | C_0603_1608Metric | 6 | 4µ7/10V
16 | C93,C86,C66,C56,C76 | C_0402_1005Metric | 5 | 1n
17 | C75,C55,C65,C85 | C_0402_1005Metric | 4 | 1n5
18 | R8,R52,R72,R62,R9,R82 | R_0402_1005Metric | 6 | 680k
19 | U50,U80,U60,U70 | TSSOP-16_4.4x5mm_P0.65mm | 4 | 74HCT4053
20 | U53,U73,U83,U63 | MSOP-10_3x3mm_P0.5mm | 4 | TLV9052S
21 | R67,R87,R77,R57 | R_0402_1005Metric | 4 | 6k2
22 | R83,R73,R63,R53 | R_0402_1005Metric | 4 | 48k7
23 | R98,R96,R97,R99 | R_0402_1005Metric | 4 | 150R
24 | D93,D94 | SOT-523 | 2 | BAV99T
25 | C70,C60,C50,C80 | C_0402_1005Metric | 4 | 1µ
26 | C53,C83,C63,C73 | C_0603_1608Metric | 4 | 1µ5
27 | C72,C62,C82,C52 | C_0603_1608Metric | 4 | 2µ2
28 | D42,D12,D22,D32 | LED_0402_1005Metric | 4 | Red
29 | TP4 | TestPoint_Pad_D1.0mm | 1 | AESD
30 | R36,R46,R26,R16 | R_0402_1005Metric | 4 | 12k
31 | L60,L80,L70,L50 | Coupled_Choke_Wuerth_74488540250 | 4 | Würth 74488540250
32 | C3,C4 | C_0603_1608Metric | 2 | 10µ/6V3
33 | J98 | U.FL_Hirose_U.FL-R-SMT-1_Vertical | 1 | WCK Out
34 | R68,R78,R58,R88 | R_0402_1005Metric | 4 | 10k
35 | R25,R94,R45 | R_0402_1005Metric | 3 | 1k5
36 | R55,R75,R85,R65 | R_0402_1005Metric | 4 | 4k7
37 | TP8 | TestPoint_Pad_D1.0mm | 1 | RDYD
38 | R86,R56,R76,R66 | R_0402_1005Metric | 4 | 2k
39 | R20,R10,R40,R30 | R_0402_1005Metric | 4 | 110R
40 | D82,D52,D72,D62 | D_SMF | 4 | SMF15A
41 | U4 | WDFN-12-1EP_3x3mm_P0.45mm_EP1.7x2.5mm | 1 | PAM2306AYPKE
42 | U71,U61,U51,U81 | SOT-23-6 | 4 | TLV61046ADB
43 | L71,L51,L61,L81 | L_Wuerth_MAPI-2512 | 4 | 10µ
44 | D84,D54,D74,D64 | LED_0402_1005Metric | 4 | Yellow
45 | U52,U62,U82,U72 | SOT-143 | 4 | MIC4417
46 | U40,U10,U30,U20 | TQFP-48_7x7mm_P0.5mm | 4 | SRC4392xPFB
47 | TP5 | TestPoint_Pad_D1.0mm | 1 | RDYA
48 | R15,R17 | R_0402_1005Metric | 2 | DNP
49 | TP7 | TestPoint_Pad_D1.0mm | 1 | RDYC
50 | U5 | SOT-563 | 1 | SN74LVC1T45DRL
51 | U3 | SOT-23-5 | 1 | AT24CS32-STUM
52 | TP9 | TestPoint_Pad_D1.0mm | 1 | XO
53 | TP1 | TestPoint_Pad_D1.0mm | 1 | AESA
54 | Y1 | Crystal_SMD_3225-4Pin_3.2x2.5mm | 1 | 10 MHz
55 | TP2 | TestPoint_Pad_D1.0mm | 1 | AESB
56 | C90 | C_0402_1005Metric | 1 | 100p
57 | J1 | Raspberry_Pi_HAT | 1 | Raspberry_Pi_2_3
58 | C94 | C_0402_1005Metric | 1 | 2p
59 | D91 | LED_0402_1005Metric | 1 | Green
60 | TP10 | TestPoint_Pad_D1.0mm | 1 | WP
61 | TP3 | TestPoint_Pad_D1.0mm | 1 | AESC
62 | R3 | R_0402_1005Metric | 1 | 1k
63 | J93 | U.FL_Hirose_U.FL-R-SMT-1_Vertical | 1 | Ref
64 | R93 | R_0402_1005Metric | 1 | 51R
65 | L4 | L_Wuerth_MAPI-2010 | 1 | 2µ2
66 | U1 | QFN-48-1EP_7x7mm_P0.5mm_EP5.1x5.1mm | 1 | LPC865M201JHI48
67 | U6 | SOT-353_SC-70-5 | 1 | SN74LV1T125DCK
68 | J8 | PinHeader_1x03_P2.54mm_Vertical | 1 | Conn_01x03_Male
69 | U2 | MSOP-10_3x3mm_P0.5mm | 1 | CS2000-CP
70 | J94 | U.FL_Hirose_U.FL-R-SMT-1_Vertical | 1 | WCK In

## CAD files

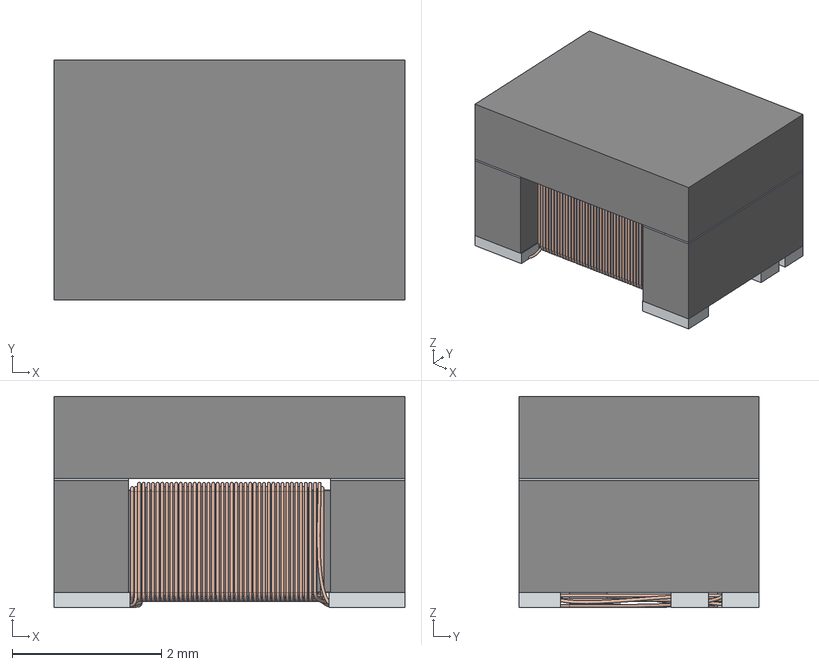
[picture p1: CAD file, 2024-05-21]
hw/Wuerth_74930030.stp
4.70 x 3.22 x 2.83 mm
Core
Windings_02
Pins
Glue
Upper Plate

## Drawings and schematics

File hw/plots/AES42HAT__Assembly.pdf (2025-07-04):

1 | 2 | 3 | 4 | 5 | 6

A

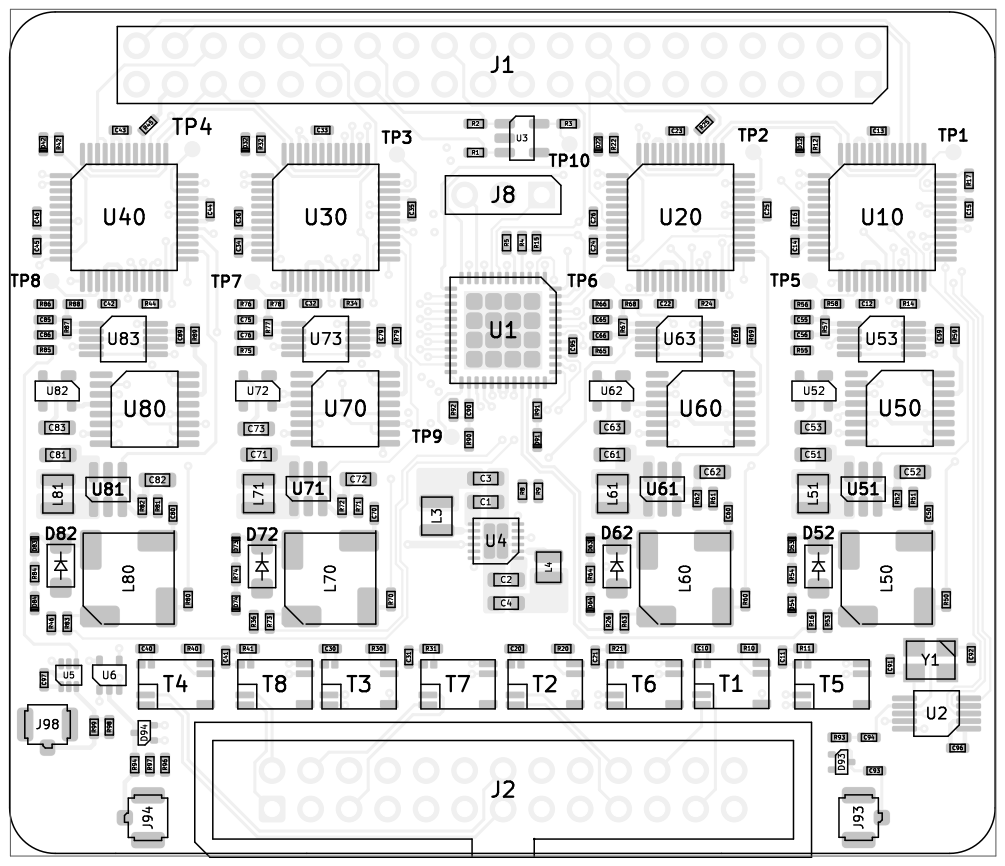
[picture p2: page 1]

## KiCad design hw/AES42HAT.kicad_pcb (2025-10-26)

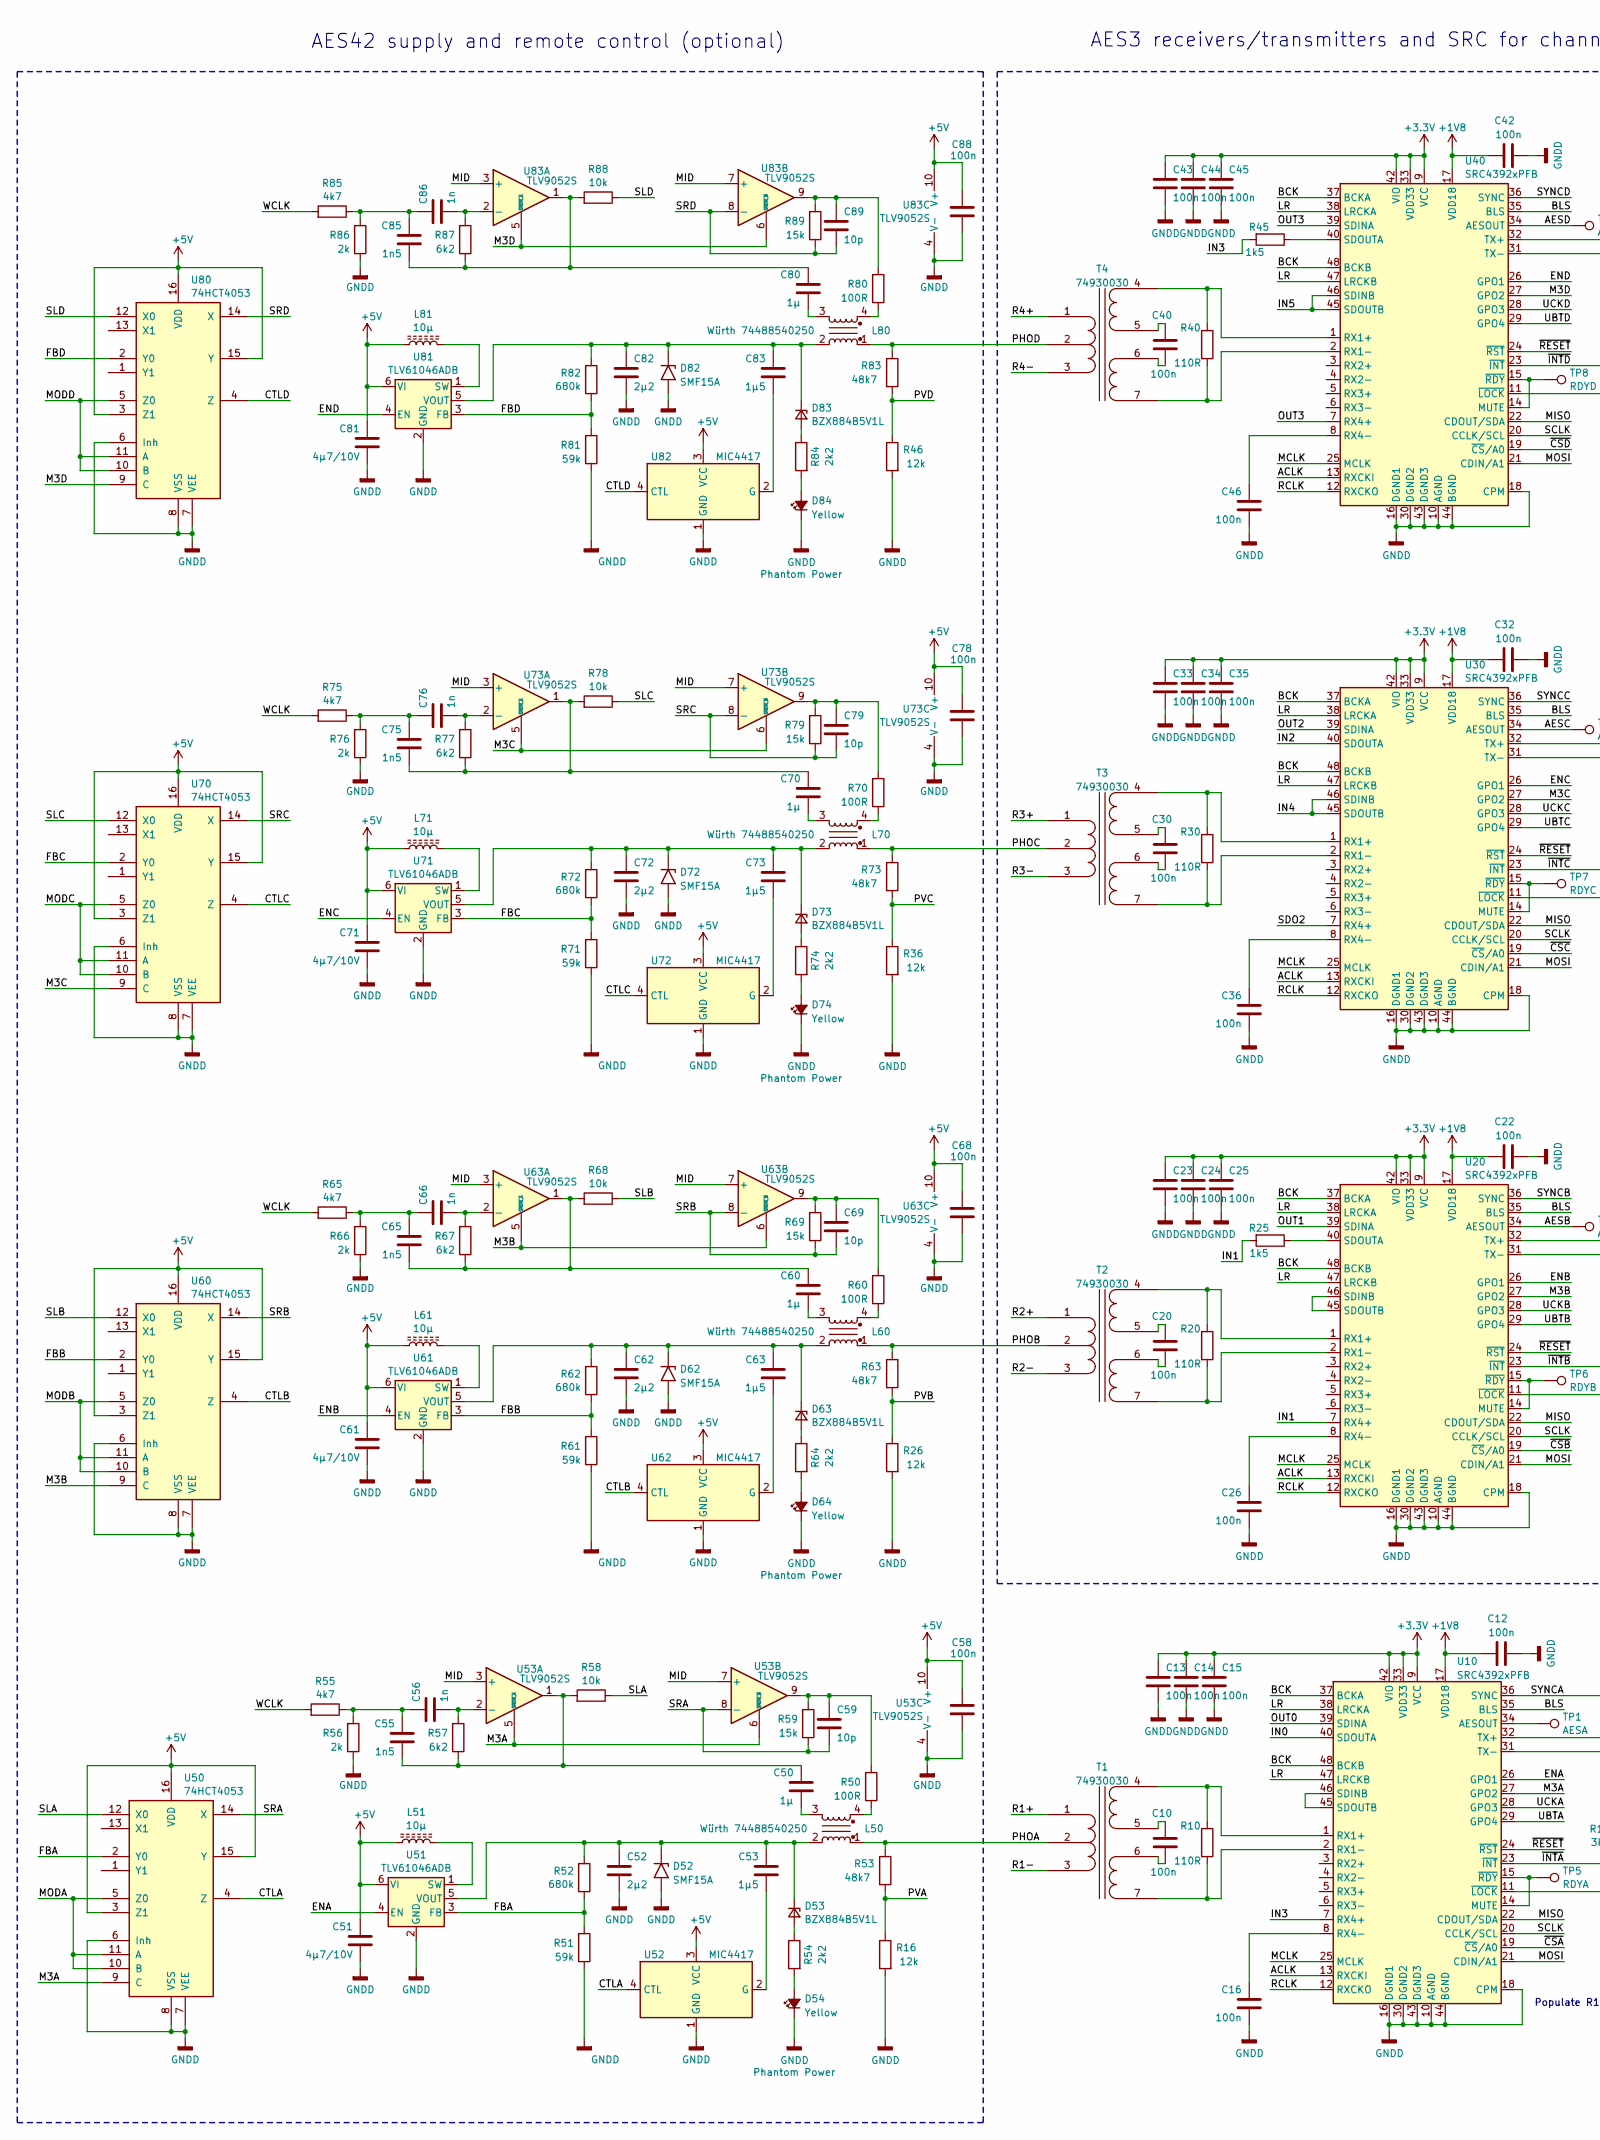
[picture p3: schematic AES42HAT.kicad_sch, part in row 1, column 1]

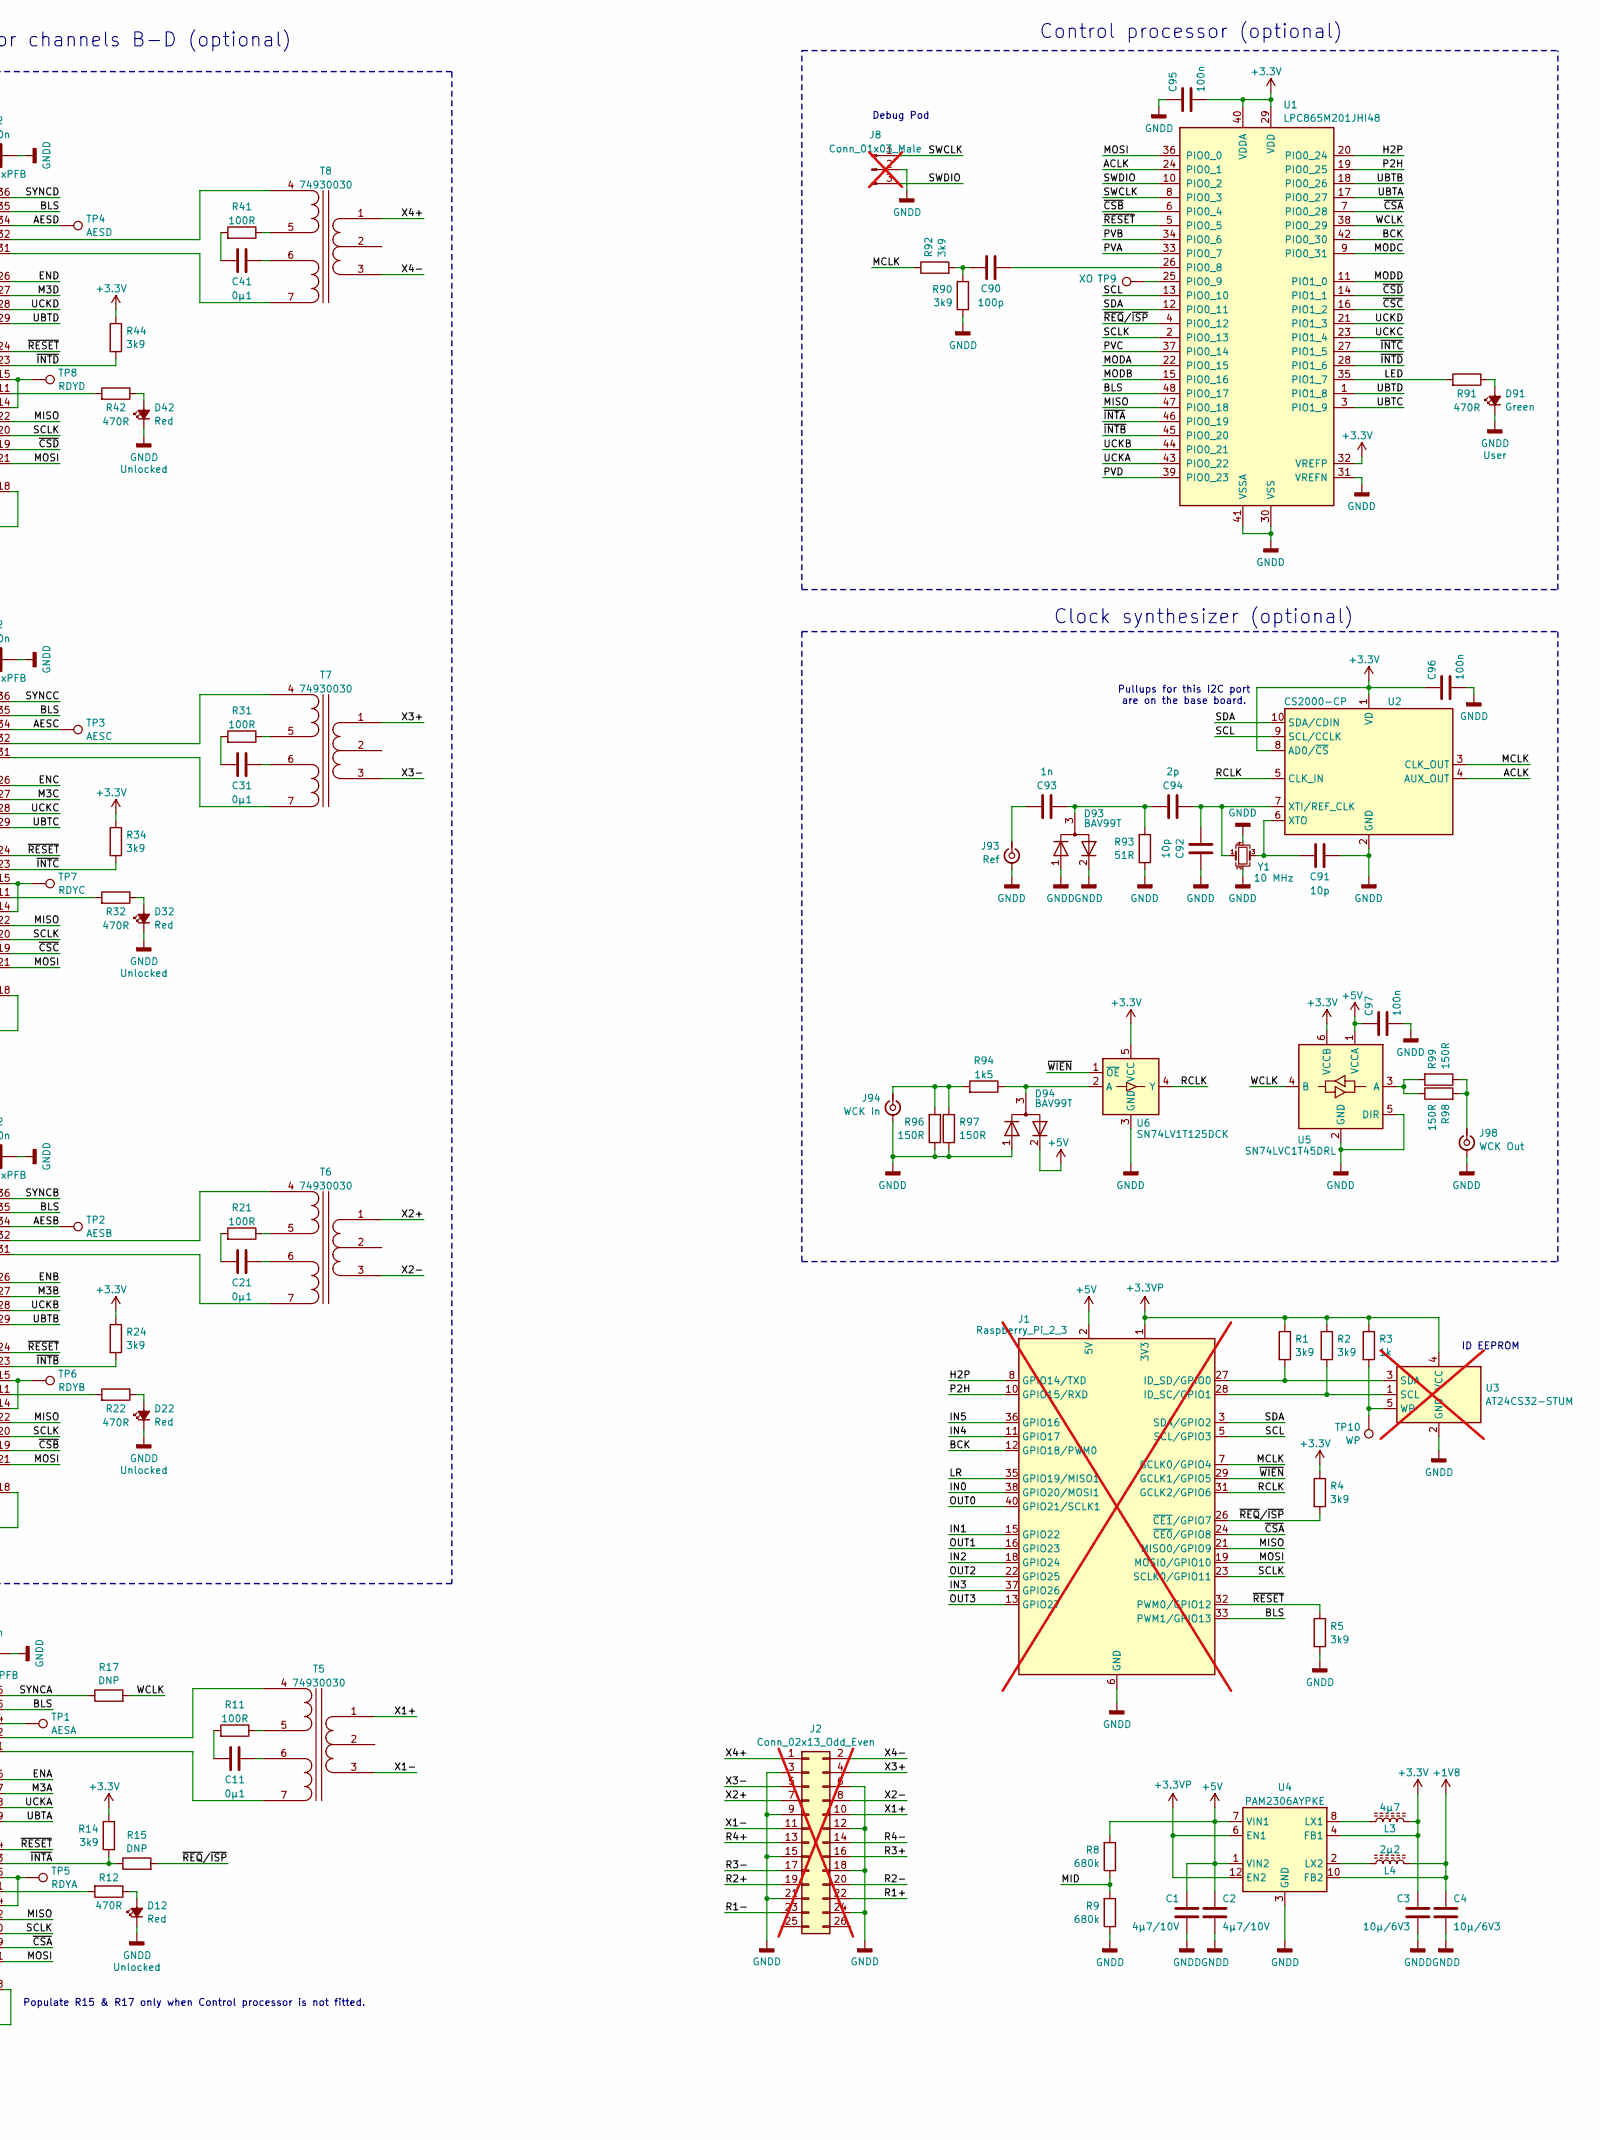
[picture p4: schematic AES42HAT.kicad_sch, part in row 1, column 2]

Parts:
C1, C2, C51, C61, C71, C81: 4µ7/10V; C_0603_1608Metric
C3, C4: 10µ/6V3; C_0603_1608Metric
C10, C12, C13, C14, C15, C16, C20, C22, C23, C24, C25, C26, C30, C32, C33, C34, C35, C36, C40, C42, C43, C44, C45, C46, C58, C68, C78, C88, C95, C96, C97: 100n; C_0402_1005Metric
C11, C21, C31, C41: 0µ1; C_0402_1005Metric
C50, C60, C70, C80: 1µ; C_0402_1005Metric
C52, C62, C72, C82: 2µ2; C_0603_1608Metric
C53, C63, C73, C83: 1µ5; C_0603_1608Metric
C55, C65, C75, C85: 1n5; C_0402_1005Metric
C56, C66, C76, C86, C93: 1n; C_0402_1005Metric
C59, C69, C79, C89, C91, C92: 10p; C_0402_1005Metric
C90: 100p; C_0402_1005Metric
C94: 2p; C_0402_1005Metric
D12, D22, D32, D42: Red; LED_0402_1005Metric
D52, D62, D72, D82: SMF15A; D_SMF
D53, D63, D73, D83: BZX884B5V1L; D_0402_1005Metric
D54, D64, D74, D84: Yellow; LED_0402_1005Metric
D91: Green; LED_0402_1005Metric
D93, D94: BAV99T; SOT-523
J1: Raspberry_Pi_2_3; Raspberry_Pi_HAT; not fitted
J2: Conn_02x13_Odd_Even; IDC-Header_2x13_P2.54mm_Vertical; not fitted
J8: Conn_01x03_Male; PinHeader_1x03_P2.54mm_Vertical; not fitted
J93: Ref; U.FL_Hirose_U.FL-R-SMT-1_Vertical
J94: WCK In; U.FL_Hirose_U.FL-R-SMT-1_Vertical
J98: WCK Out; U.FL_Hirose_U.FL-R-SMT-1_Vertical
L3: 4µ7; L_Wuerth_MAPI-2512
L4: 2µ2; L_Wuerth_MAPI-2010
L50, L60, L70, L80: Würth 74488540250; Coupled_Choke_Wuerth_74488540250
L51, L61, L71, L81: 10µ; L_Wuerth_MAPI-2512
R1, R2, R4, R5, R14, R24, R34, R44, R90, R92: 3k9; R_0402_1005Metric
R3: 1k; R_0402_1005Metric
R8, R9, R52, R62, R72, R82: 680k; R_0402_1005Metric
R10, R20, R30, R40: 110R; R_0402_1005Metric
R11, R21, R31, R41, R50, R60, R70, R80: 100R; R_0402_1005Metric
R12, R22, R32, R42, R91: 470R; R_0402_1005Metric
R15, R17: DNP; R_0402_1005Metric
R16, R26, R36, R46: 12k; R_0402_1005Metric
R25, R45, R94: 1k5; R_0402_1005Metric
R51, R61, R71, R81: 59k; R_0402_1005Metric
R53, R63, R73, R83: 48k7; R_0402_1005Metric
R54, R64, R74, R84: 2k2; R_0402_1005Metric
R55, R65, R75, R85: 4k7; R_0402_1005Metric
R56, R66, R76, R86: 2k; R_0402_1005Metric
R57, R67, R77, R87: 6k2; R_0402_1005Metric
R58, R68, R78, R88: 10k; R_0402_1005Metric
R59, R69, R79, R89: 15k; R_0402_1005Metric
R93: 51R; R_0402_1005Metric
R96, R97, R98, R99: 150R; R_0402_1005Metric
T1, T2, T3, T4, T5, T6, T7, T8: 74930030; Transformer_Wuerth_74930030
TP1: AESA; TestPoint_Pad_D1.0mm
TP2: AESB; TestPoint_Pad_D1.0mm
TP3: AESC; TestPoint_Pad_D1.0mm
TP4: AESD; TestPoint_Pad_D1.0mm
TP5: RDYA; TestPoint_Pad_D1.0mm
TP6: RDYB; TestPoint_Pad_D1.0mm
TP7: RDYC; TestPoint_Pad_D1.0mm
TP8: RDYD; TestPoint_Pad_D1.0mm
TP9: XO; TestPoint_Pad_D1.0mm
TP10: WP; TestPoint_Pad_D1.0mm
U1: LPC865M201JHI48; QFN-48-1EP_7x7mm_P0.5mm_EP5.1x5.1mm
U2: CS2000-CP; MSOP-10_3x3mm_P0.5mm
U3: AT24CS32-STUM; SOT-23-5; not fitted
U4: PAM2306AYPKE; WDFN-12-1EP_3x3mm_P0.45mm_EP1.7x2.5mm
U5: SN74LVC1T45DRL; SOT-563
U6: SN74LV1T125DCK; SOT-353_SC-70-5
U10, U20, U30, U40: SRC4392xPFB; TQFP-48_7x7mm_P0.5mm
U50, U60, U70, U80: 74HCT4053; TSSOP-16_4.4x5mm_P0.65mm
U51, U61, U71, U81: TLV61046ADB; SOT-23-6
U52, U62, U72, U82: MIC4417; SOT-143
U53, U63, U73, U83: TLV9052S; MSOP-10_3x3mm_P0.5mm
Y1: 10 MHz; Crystal_SMD_3225-4Pin_3.2x2.5mm

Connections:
+1V8: C4.1, C12.1, C22.1, C32.1, C42.1, L4.2, U4.10 (FB2), U10.17 (VDD18), U20.17 (VDD18), U30.17 (VDD18), U40.17 (VDD18)
+3.3V: C3.1, C13.1, C14.1, C15.1, C23.1, C24.1, C25.1, C33.1, C34.1, C35.1, C43.1, C44.1, C45.1, C95.2, C96.1, J1.5 (VCC), L3.2, R4.1, R14.1, R24.1, R34.1, R44.1, U1.29 (VDD), U1.32 (VREFP), U1.40 (VDDA), U2.1 (VD), U2.8 (AD0/~CS), U4.4 (FB1), U5.6 (VCCB), U6.5 (VCC), U10.9 (VCC), U10.33 (VDD33), U10.42 (VIO), U20.9 (VCC), U20.33 (VDD33), U20.42 (VIO), U30.9 (VCC), U30.33 (VDD33), U30.42 (VIO), U40.9 (VCC), U40.33 (VDD33), U40.42 (VIO)
+3.3VP: J1.1 (3V3), J1.17 (3V3), R1.1, R2.1, R3.1, U3.4 (VCC), U4.6 (EN1), U4.12 (EN2)
/ACLK: U1.24 (PIO0_1), U2.4 (AUX_OUT), U10.13 (RXCKI), U20.13 (RXCKI), U30.13 (RXCKI), U40.13 (RXCKI)
/AESB: TP2.1, U20.34 (AESOUT)
/AESC: TP3.1, U30.34 (AESOUT)
/AESD: TP4.1, U40.34 (AESOUT)
/BCK: J1.12 (GPIO18/PWM0), U1.42 (PIO0_30), U10.37 (BCKA), U10.48 (BCKB), U20.37 (BCKA), U20.48 (BCKB), U30.37 (BCKA), U30.48 (BCKB), U40.37 (BCKA), U40.48 (BCKB)
/BLS: J1.33 (PWM1/GPIO13), U1.48 (PIO0_17), U10.35 (BLS), U20.35 (BLS), U30.35 (BLS), U40.35 (BLS)
/CTLA: U50.4 (Z), U52.4 (CTL)
/CTLB: U60.4 (Z), U62.4 (CTL)
/CTLC: U70.4 (Z), U72.4 (CTL)
/CTLD: U80.4 (Z), U82.4 (CTL)
/ENA: U10.26 (GPO1), U51.4 (EN)
/ENB: U20.26 (GPO1), U61.4 (EN)
/ENC: U30.26 (GPO1), U71.4 (EN)
/END: U40.26 (GPO1), U81.4 (EN)
/FBA: R51.2, R52.1, U50.2 (Y0), U51.3 (FB)
/FBB: R61.2, R62.1, U60.2 (Y0), U61.3 (FB)
/FBC: R71.2, R72.1, U70.2 (Y0), U71.3 (FB)
/FBD: R81.2, R82.1, U80.2 (Y0), U81.3 (FB)
/H2P: J1.8 (GPIO14/TXD), U1.20 (PIO0_24)
/IN0: J1.38 (GPIO20/MOSI1), U10.40 (SDOUTA)
/IN1: J1.15 (GPIO22), R25.2, U20.7 (RX4+)
/IN2: J1.18 (GPIO24), U30.40 (SDOUTA)
/IN3: J1.37 (GPIO26), R45.2, U10.7 (RX4+)
/IN4: J1.11 (GPIO17), U30.45 (SDOUTB), U30.46 (SDINB)
/IN5: J1.36 (GPIO16), U40.45 (SDOUTB), U40.46 (SDINB)
/LED: R91.2, U1.35 (PIO1_7)
/LR: J1.35 (GPIO19/MISO1), U10.38 (LRCKA), U10.47 (LRCKB), U20.38 (LRCKA), U20.47 (LRCKB), U30.38 (LRCKA), U30.47 (LRCKB), U40.38 (LRCKA), U40.47 (LRCKB)
/M3A: U10.27 (GPO2), U50.9 (C), U53.5 (~SHDN_A), U53.6 (~SHDN_B)
/M3B: U20.27 (GPO2), U60.9 (C), U63.5 (~SHDN_A), U63.6 (~SHDN_B)
/M3C: U30.27 (GPO2), U70.9 (C), U73.5 (~SHDN_A), U73.6 (~SHDN_B)
/M3D: U40.27 (GPO2), U80.9 (C), U83.5 (~SHDN_A), U83.6 (~SHDN_B)
/MCLK: J1.7 (GCLK0/GPIO4), R92.1, U2.3 (CLK_OUT), U10.25 (MCLK), U20.25 (MCLK), U30.25 (MCLK), U40.25 (MCLK)
/MID: R8.1, R9.2, U53.3 (+), U53.7 (+), U63.3 (+), U63.7 (+), U73.3 (+), U73.7 (+), U83.3 (+), U83.7 (+)
/MISO: J1.21 (MISO0/GPIO9), U1.47 (PIO0_18), U10.22 (CDOUT/SDA), U20.22 (CDOUT/SDA), U30.22 (CDOUT/SDA), U40.22 (CDOUT/SDA)
/MODA: U1.22 (PIO0_15), U50.5 (Z0), U50.10 (B), U50.11 (A)
/MODB: U1.15 (PIO0_16), U60.5 (Z0), U60.10 (B), U60.11 (A)
/MODC: U1.9 (PIO0_31), U70.5 (Z0), U70.10 (B), U70.11 (A)
/MODD: U1.11 (PIO1_0), U80.5 (Z0), U80.10 (B), U80.11 (A)
/MOSI: J1.19 (MOSI0/GPIO10), U1.36 (PIO0_0), U10.21 (CDIN/A1), U20.21 (CDIN/A1), U30.21 (CDIN/A1), U40.21 (CDIN/A1)
/OUT0: J1.40 (GPIO21/SCLK1), U10.39 (SDINA)
/OUT1: J1.16 (GPIO23), U20.39 (SDINA)
/OUT2: J1.22 (GPIO25), U30.39 (SDINA)
/OUT3: J1.13 (GPIO27), U40.7 (RX4+), U40.39 (SDINA)
/P2H: J1.10 (GPIO15/RXD), U1.19 (PIO0_25)
/PHOA: L50.1, R53.1, T1.2 (PM)
/PHOB: L60.1, R63.1, T2.2 (PM)
/PHOC: L70.1, R73.1, T3.2 (PM)
/PHOD: L80.1, R83.1, T4.2 (PM)
/PVA: R16.1, R53.2, U1.33 (PIO0_7)
/PVB: R26.1, R63.2, U1.34 (PIO0_6)
/PVC: R36.1, R73.2, U1.37 (PIO0_14)
/PVD: R46.1, R83.2, U1.39 (PIO0_23)
/R1+: J2.22, T1.1 (IN+)
/R1-: J2.23, T1.3 (IN-)
/R2+: J2.19, T2.1 (IN+)
/R2-: J2.20, T2.3 (IN-)
/R3+: J2.16, T3.1 (IN+)
/R3-: J2.17, T3.3 (IN-)
/R4+: J2.13, T4.1 (IN+)
/R4-: J2.14, T4.3 (IN-)
/SCL: J1.5 (SCL/GPIO3), U1.13 (PIO0_10), U2.9 (SCL/CCLK)
/SCLK: J1.23 (SCLK0/GPIO11), U1.2 (PIO0_13), U10.20 (CCLK/SCL), U20.20 (CCLK/SCL), U30.20 (CCLK/SCL), U40.20 (CCLK/SCL)
/SDA: J1.3 (SDA/GPIO2), U1.12 (PIO0_11), U2.10 (SDA/CDIN)
/SDO2: U30.7 (RX4+)
/SLA: R58.1, U50.12 (X0)
/SLB: R68.1, U60.12 (X0)
/SLC: R78.1, U70.12 (X0)
/SLD: R88.1, U80.12 (X0)
/SRA: C59.2, R59.1, U50.14 (X), U53.8 (-)
/SRB: C69.2, R69.1, U60.14 (X), U63.8 (-)
/SRC: C79.2, R79.1, U70.14 (X), U73.8 (-)
/SRD: C89.2, R89.1, U80.14 (X), U83.8 (-)
/SWCLK: J8.1, U1.8 (PIO0_3)
/SWDIO: J8.3, U1.10 (PIO0_2)
/SYNCA: R17.1, U10.36 (SYNC)
/SYNCB: U20.36 (SYNC)
/SYNCC: U30.36 (SYNC)
/SYNCD: U40.36 (SYNC)
/UBTA: U1.17 (PIO0_27), U10.29 (GPO4)
/UBTB: U1.18 (PIO0_26), U20.29 (GPO4)
/UBTC: U1.3 (PIO1_9), U30.29 (GPO4)
/UBTD: U1.1 (PIO1_8), U40.29 (GPO4)
/UCKA: U1.43 (PIO0_22), U10.28 (GPO3)
/UCKB: U1.44 (PIO0_21), U20.28 (GPO3)
/UCKC: U1.23 (PIO1_4), U30.28 (GPO3)
/UCKD: U1.21 (PIO1_3), U40.28 (GPO3)
/WCLK: R17.2, R55.2, R65.2, R75.2, R85.2, U1.38 (PIO0_29), U5.4 (B)
/X1+: J2.10, T5.1 (IN+)
/X1-: J2.11, T5.3 (IN-)
/X2+: J2.7, T6.1 (IN+)
/X2-: J2.8, T6.3 (IN-)
/X3+: J2.4, T7.1 (IN+)
/X3-: J2.5, T7.3 (IN-)
/X4+: J2.1, T8.1 (IN+)
/X4-: J2.2, T8.3 (IN-)
/~CSA: J1.24 (~CE0/GPIO8), U1.7 (PIO0_28), U10.19 (~CS/A0)
/~CSB: U1.6 (PIO0_4), U20.19 (~CS/A0)
/~CSC: U1.16 (PIO1_2), U30.19 (~CS/A0)
/~CSD: U1.14 (PIO1_1), U40.19 (~CS/A0)
/~INTA: R14.2, R15.1, U1.46 (PIO0_19), U10.23 (~INT)
/~INTB: R24.2, U1.45 (PIO0_20), U20.23 (~INT)
/~INTC: R34.2, U1.27 (PIO1_5), U30.23 (~INT)
/~INTD: R44.2, U1.28 (PIO1_6), U40.23 (~INT)
/~REQ/~ISP: J1.26 (~CE1/GPIO7), R4.2, R15.2, U1.4 (PIO0_12)
/~RESET: J1.32 (PWM0/GPIO12), R5.1, U1.5 (PIO0_5), U10.24 (~RST), U20.24 (~RST), U30.24 (~RST), U40.24 (~RST)
/~WIEN: J1.29 (GCLK1/GPIO5), U6.1 (~OE)
GNDD: C1.2, C2.2, C3.2, C4.2, C12.2, C13.2, C14.2, C15.2, C16.2, C22.2, C23.2, C24.2, C25.2, C26.2, C32.2, C33.2, C34.2, C35.2, C36.2, C42.2, C43.2, C44.2, C45.2, C46.2, C51.2, C52.2, C58.2, C61.2, C62.2, C68.2, C71.2, C72.2, C78.2, C81.2, C82.2, C88.2, C91.1, C92.2, C95.1, C96.2, C97.2, D12.1 (K), D22.1 (K), D32.1 (K), D42.1 (K), D52.2 (A2), D54.1 (K), D62.2 (A2), D64.1 (K), D72.2 (A2), D74.1 (K), D82.2 (A2), D84.1 (K), D91.1 (K), D93.1 (K), D93.2 (K), D94.1 (K), J1.6 (GND), J1.9 (GND), J1.14 (GND), J1.20 (GND), J1.25 (GND), J1.30 (GND), J1.34 (GND), J1.39 (GND), J2.3, J2.6, J2.9, J2.12, J2.15, J2.18, J2.21, J2.24, J8.2, J93.2 (Ext), J94.2 (Ext), J98.2 (Ext), R5.2, R9.1, R16.2, R26.2, R36.2, R46.2, R51.1, R56.1, R61.1, R66.1, R71.1, R76.1, R81.1, R86.1, R90.2, R93.1, R96.1, R97.1, U1.30 (VSS), U1.31 (VREFN), U1.41 (VSSA), U2.2 (GND), U3.2 (GND), U4.3 (GND), U4.9 (GND), U4.13 (GND), U5.2 (GND), U5.5 (DIR), U6.3 (GND), U10.10 (AGND), U10.16 (DGND1), U10.18 (CPM), U10.30 (DGND2), U10.43 (DGND3), U10.44 (BGND), U20.10 (AGND), U20.16 (DGND1), U20.18 (CPM), U20.30 (DGND2), U20.43 (DGND3), U20.44 (BGND), U30.10 (AGND), U30.16 (DGND1), U30.18 (CPM), U30.30 (DGND2), U30.43 (DGND3), U30.44 (BGND), U40.10 (AGND), U40.16 (DGND1), U40.18 (CPM), U40.30 (DGND2), U40.43 (DGND3), U40.44 (BGND), U50.6 (Inh), U50.7 (VEE), U50.8 (VSS), U51.2 (GND), U52.1 (GND), U53.4 (V-), U53.11 (V-), U60.6 (Inh), U60.7 (VEE), U60.8 (VSS), U61.2 (GND), U62.1 (GND), U63.4 (V-), U63.11 (V-), U70.6 (Inh), U70.7 (VEE), U70.8 (VSS), U71.2 (GND), U72.1 (GND), U73.4 (V-), U73.11 (V-), U80.6 (Inh), U80.7 (VEE), U80.8 (VSS), U81.2 (GND), U82.1 (GND), U83.4 (V-), U83.11 (V-), Y1.2, Y1.4
unnamed: C11.2, R11.2
unnamed: C21.2, R21.2
unnamed: C31.2, R31.2
unnamed: C41.2, R41.2
unnamed: C50.1, C55.2, R57.1, R58.2, U53.1
unnamed: C50.2, L50.3
unnamed: C55.1, C56.1, R55.1, R56.2
unnamed: C59.1, R50.2, R59.2, U53.9
unnamed: C60.1, C65.2, R67.1, R68.2, U63.1
unnamed: C60.2, L60.3
unnamed: C65.1, C66.1, R65.1, R66.2
unnamed: C69.1, R60.2, R69.2, U63.9
unnamed: C70.1, C75.2, R77.1, R78.2, U73.1
unnamed: C70.2, L70.3
unnamed: C75.1, C76.1, R75.1, R76.2
unnamed: C79.1, R70.2, R79.2, U73.9
unnamed: C80.1, C85.2, R87.1, R88.2, U83.1
unnamed: C80.2, L80.3
unnamed: C85.1, C86.1, R85.1, R86.2
unnamed: C89.1, R80.2, R89.2, U83.9
unnamed: C90.2, R90.1, R92.2
unnamed: D12.2 (A), R12.1
unnamed: D22.2 (A), R22.1
unnamed: D32.2 (A), R32.1
unnamed: D42.2 (A), R42.1
unnamed: C52.1, C53.1, D52.1 (A1), D53.1 (K), L50.2, R52.2, U51.5 (VOUT)
unnamed: D53.2 (A), R54.1
unnamed: D54.2 (A), R54.2
unnamed: C62.1, C63.1, D62.1 (A1), D63.1 (K), L60.2, R62.2, U61.5 (VOUT)
unnamed: D63.2 (A), R64.1
unnamed: D64.2 (A), R64.2
unnamed: C72.1, C73.1, D72.1 (A1), D73.1 (K), L70.2, R72.2, U71.5 (VOUT)
unnamed: D73.2 (A), R74.1
unnamed: D74.2 (A), R74.2
unnamed: C82.1, C83.1, D82.1 (A1), D83.1 (K), L80.2, R82.2, U81.5 (VOUT)
unnamed: D83.2 (A), R84.1
unnamed: D84.2 (A), R84.2
unnamed: D91.2 (A), R91.1
unnamed: C93.1, C94.2, D93.3 (A), R93.2
unnamed: D94.3 (A), R94.1, U6.2 (A)
unnamed: J1.28 (ID_SC/GPIO1), R2.2, U3.1 (SCL)
unnamed: J1.27 (ID_SD/GPIO0), R1.2, U3.3 (SDA)
unnamed: C93.2, J93.1 (In)
unnamed: J94.1 (In), R94.2, R96.2, R97.2
unnamed: J98.1 (In), R98.2, R99.1
unnamed: L50.4, R50.1
unnamed: L60.4, R60.1
unnamed: L70.4, R70.1
unnamed: L80.4, R80.1
unnamed: R10.1, T1.4 (OUT1A), U10.1 (RX1+)
unnamed: C10.1, T1.5 (OUT1B)
unnamed: C10.2, T1.6 (OUT2A)
unnamed: R10.2, T1.7 (OUT2B), U10.2 (RX1-)
unnamed: R20.1, T2.4 (OUT1A), U20.1 (RX1+)
unnamed: C20.1, T2.5 (OUT1B)
unnamed: C20.2, T2.6 (OUT2A)
unnamed: R20.2, T2.7 (OUT2B), U20.2 (RX1-)
unnamed: R30.1, T3.4 (OUT1A), U30.1 (RX1+)
unnamed: C30.1, T3.5 (OUT1B)
unnamed: C30.2, T3.6 (OUT2A)
unnamed: R30.2, T3.7 (OUT2B), U30.2 (RX1-)
unnamed: R40.1, T4.4 (OUT1A), U40.1 (RX1+)
unnamed: C40.1, T4.5 (OUT1B)
unnamed: C40.2, T4.6 (OUT2A)
unnamed: R40.2, T4.7 (OUT2B), U40.2 (RX1-)
unnamed: T5.4 (OUT1A), U10.32 (TX+)
unnamed: R11.1, T5.5 (OUT1B)
unnamed: C11.1, T5.6 (OUT2A)
unnamed: T5.7 (OUT2B), U10.31 (TX-)
unnamed: T6.4 (OUT1A), U20.32 (TX+)
unnamed: R21.1, T6.5 (OUT1B)
unnamed: C21.1, T6.6 (OUT2A)
unnamed: T6.7 (OUT2B), U20.31 (TX-)
unnamed: T7.4 (OUT1A), U30.32 (TX+)
unnamed: R31.1, T7.5 (OUT1B)
unnamed: C31.1, T7.6 (OUT2A)
unnamed: T7.7 (OUT2B), U30.31 (TX-)
unnamed: T8.4 (OUT1A), U40.32 (TX+)
unnamed: R41.1, T8.5 (OUT1B)
unnamed: C41.1, T8.6 (OUT2A)
unnamed: T8.7 (OUT2B), U40.31 (TX-)
unnamed: C90.1, U1.26 (PIO0_8)
unnamed: TP9.1, U1.25 (PIO0_9)
unnamed: C92.1, C94.1, U2.7 (XTI/REF_CLK), Y1.1
unnamed: C91.2, U2.6 (XTO), Y1.3
unnamed: R3.2, TP10.1, U3.5 (WP)
unnamed: L3.1, U4.8 (LX1)
unnamed: L4.1, U4.2 (LX2)
unnamed: R98.1, R99.2, U5.3 (A)
unnamed: TP1.1, U10.34 (AESOUT)
unnamed: TP5.1, U10.14 (MUTE), U10.15 (~RDY)
unnamed: C16.1, U10.8 (RX4-)
unnamed: U10.45 (SDOUTB), U10.46 (SDINB)
unnamed: R12.2, U10.11 (~LOCK)
unnamed: TP6.1, U20.14 (MUTE), U20.15 (~RDY)
unnamed: C26.1, U20.8 (RX4-)
unnamed: U20.45 (SDOUTB), U20.46 (SDINB)
unnamed: R25.1, U20.40 (SDOUTA)
unnamed: R22.2, U20.11 (~LOCK)
unnamed: TP7.1, U30.14 (MUTE), U30.15 (~RDY)
unnamed: C36.1, U30.8 (RX4-)
unnamed: R32.2, U30.11 (~LOCK)
unnamed: TP8.1, U40.14 (MUTE), U40.15 (~RDY)
unnamed: C46.1, U40.8 (RX4-)
unnamed: R45.1, U40.40 (SDOUTA)
unnamed: R42.2, U40.11 (~LOCK)
unnamed: L51.2, U51.1 (SW)
unnamed: C53.2, U52.2 (G)
unnamed: C56.2, R57.2, U53.2 (-)
unnamed: L61.2, U61.1 (SW)
unnamed: C63.2, U62.2 (G)
unnamed: C66.2, R67.2, U63.2 (-)
unnamed: L71.2, U71.1 (SW)
unnamed: C73.2, U72.2 (G)
unnamed: C76.2, R77.2, U73.2 (-)
unnamed: L81.2, U81.1 (SW)
unnamed: C83.2, U82.2 (G)
unnamed: C86.2, R87.2, U83.2 (-)

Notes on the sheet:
Populate R15 & R17 only when Control processor is not fitted.
AES42 supply and remote control (optional)
AES3 receivers/transmitters and SRC for channels B-D (optional)
ID EEPROM
Control processor (optional)
Clock synthesizer (optional)
Pullups for this I2C port are on the base board.
Debug Pod

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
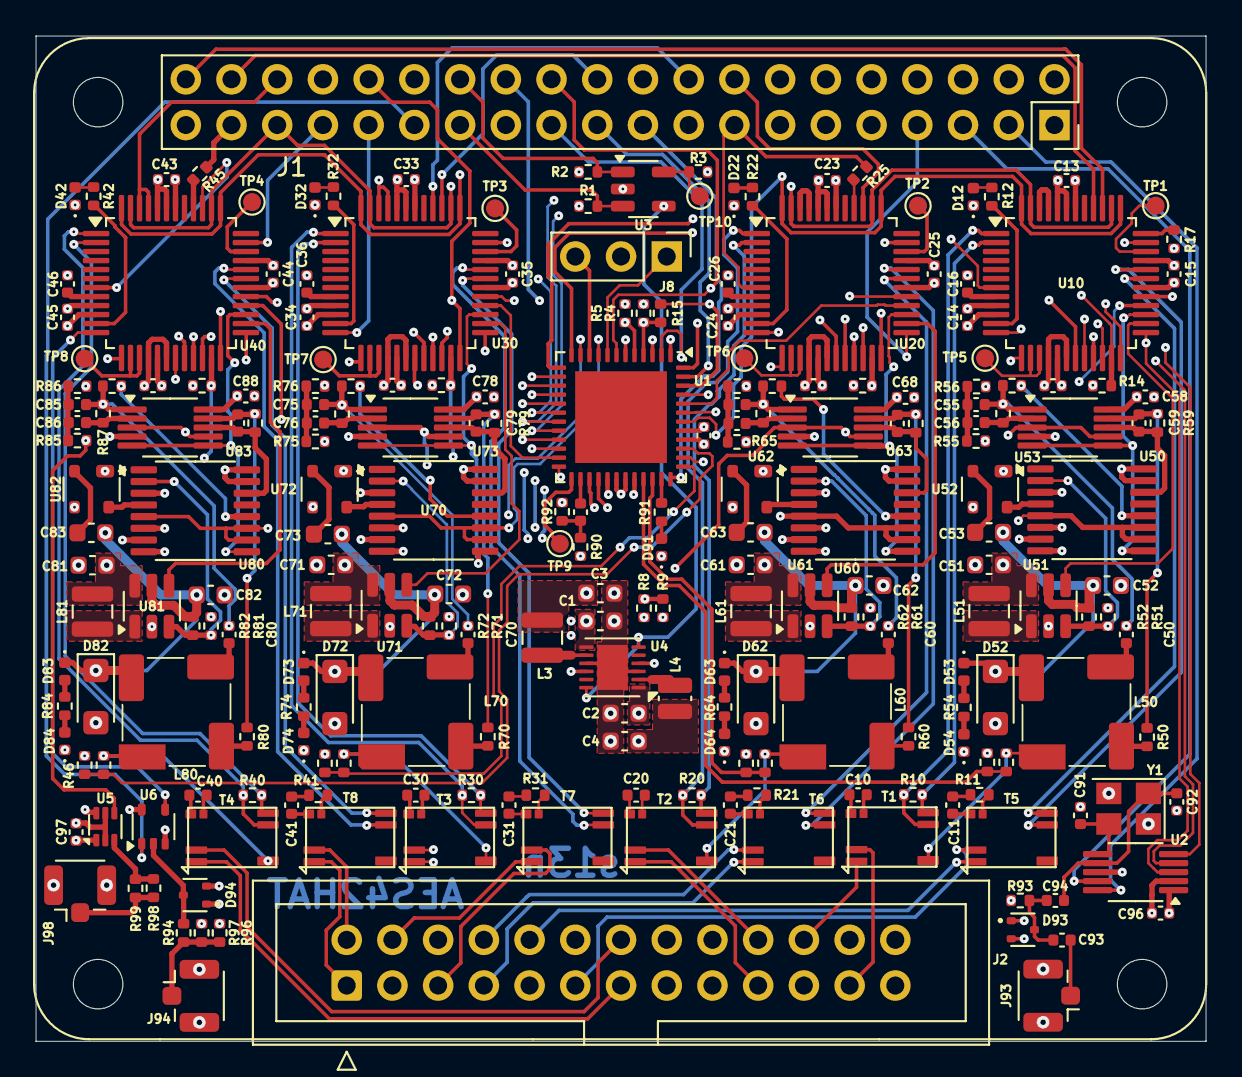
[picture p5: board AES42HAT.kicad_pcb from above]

Board: 6 copper layers, 65.0 x 55.8 mm, 232 parts (0 on the bottom side), 226 nets.

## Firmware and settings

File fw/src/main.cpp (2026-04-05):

/** @file
 * main function for the AES42HAT
 */

import dma_drv;
import ftm_drv;
import i2c_tgt_drv;
import pint_drv;
import spi_queue;
import usart_drv;
import wkt_drv;
import spi_drv;
import handler;
import clkmgr;
import channel;
import LPC865;
#include "LPC86x_clocks.hpp"
#include <string_view>

using namespace lpc865;

constexpr std::byte operator""_y(unsigned long long value) {
    return static_cast<std::byte>(value);
}

static std::initializer_list<std::byte> const srcInitData0 = {
    0x3F_y, // Register 01: Power-Down and Reset
    0x00_y, // Register 02: Global Interrupt Status (Read-Only)
    0x39_y, // Register 03: Port A Control Register 1
    0x03_y, // Register 04: Port A Control Register 2
    0x31_y, // Register 05: Port B Control Register 1
    0x00_y, // Register 06: Port B Control Register 2
    0x7D_y, // Register 07: Transmitter Control Register 1
    0x20_y, // Register 08: Transmitter Control Register 2
    0x01_y, // Register 09: Transmitter Control Register 3
    0x00_y, // Register 0A: SRC and DIT Status (Read-Only)
    0x00_y, // Register 0B: SRC and DIT Interrupt Mask Register
    0x00_y, // Register 0C: SRC and DIT Interrupt Mode Register
    0x08_y, // Register 0D: Receiver Control Register 1
    0x00_y, // Register 0E: Receiver Control Register 2
    0x22_y, // Register 0F: Receiver PLL1 Configuration Register 1
    0x00_y, // Register 10: Receiver PLL1 Configuration Register 2
    0x00_y, // Register 11: Receiver PLL1 Configuration Register 3
    0x00_y, // Register 12: Non-PCM Audio Detection Status Register (Read-Only)
    0x00_y, // Register 13: Receiver Status Register 1 (Read-Only)
    0x00_y, // Register 14: Receiver Status Register 2 (Read-Only)
    0x00_y, // Register 15: Receiver Status Register 3 (Read-Only)
    0x01_y, // Register 16: Receiver Interrupt Mask Register 1
    0x00_y, // Register 17: Receiver Interrupt Mask Register 2
    0x02_y, // Register 18: Receiver Interrupt Mode Register 1
    0x00_y, // Register 19: Receiver Interrupt Mode Register 2
    0x00_y, // Register 1A: Receiver Interrupt Mode Register 3
    0x01_y, // Register 1B: General-Purpose Output 1 (GPO1) Control Register
    0x00_y, // Register 1C: General-Purpose Output 2 (GPO2) Control Register
    0x0E_y, // Register 1D: General-Purpose Output 3 (GPO3) Control Register
    0x09_y, // Register 1E: General-Purpose Output 4 (GPO4) Control Register
    0x00_y, // Register 1F: Q-Channel Sub-Code Data Register 1 (Read-Only), Bits[7:0], Control and Address
    0x00_y, // Register 20: Q-Channel Sub-Code Data Register 2 (Read-Only), Bits[15:8], Track
    0x00_y, // Register 21: Q-Channel Sub-Code Data Register 3 (Read-Only), Bits[23:16], Index
    0x00_y, // Register 22: Q-Channel Sub-Code Data Register 4 (Read-Only), Bits[31:24], Minutes
    0x00_y, // Register 23: Q-Channel Sub-Code Data Register 5 (Read-Only), Bits[39:32], Seconds
    0x00_y, // Register 24: Q-Channel Sub-Code Data Register 6 (Read-Only), Bits[47:40], Frame
    0x00_y, // Register 25: Q-Channel Sub-Code Data Register 7 (Read-Only), Bits[55:48], Zero
    0x00_y, // Register 26: Q-Channel Sub-Code Data Register 8 (Read-Only), Bits[63:56], AMIN
    0x00_y, // Register 27: Q-Channel Sub-Code Data Register 9 (Read-Only), Bits[71:64], ASEC
    0x00_y, // Register 28: Q-Channel Sub-Code Data Register 10 (Read-Only), Bits[79:72], AFRAME
    0x00_y, // Register 29: Burst Preamble PC High-Byte Status Register (Read-Only)
    0x00_y, // Register 2A: Burst Preamble PC Low-Byte Status Register (Read-Only)
    0x00_y, // Register 2B: Burst Preamble PD High-Byte Status Register (Read-Only)
    0x00_y, // Register 2C: Burst Preamble PD Low-Byte Status Register (Read-Only)
    0x02_y, // Register 2D: SRC Control Register 1
    0x00_y, // Register 2E: SRC Control Register 2
    0x00_y, // Register 2F: SRC Control Register 3
    0x00_y, // Register 30: SRC Control Register 4
    0x00_y, // Register 31: SRC Control Register 5
    0x00_y, // Register 32: SRC Ratio Readback Register (Read-Only)
    0x00_y, // Register 33: SRC Ratio Readback Register (Read-Only)
};

static std::initializer_list<std::byte> const srcInitData = {
    0x3F_y, // Register 01: Power-Down and Reset
    0x00_y, // Register 02: Global Interrupt Status (Read-Only)
    0x31_y, // Register 03: Port A Control Register 1
    0x00_y, // Register 04: Port A Control Register 2
    0x31_y, // Register 05: Port B Control Register 1
    0x00_y, // Register 06: Port B Control Register 2
    0x79_y, // Register 07: Transmitter Control Register 1
    0x20_y, // Register 08: Transmitter Control Register 2
    0x01_y, // Register 09: Transmitter Control Register 3
    0x00_y, // Register 0A: SRC and DIT Status (Read-Only)
    0x00_y, // Register 0B: SRC and DIT Interrupt Mask Register
    0x00_y, // Register 0C: SRC and DIT Interrupt Mode Register
    0x08_y, // Register 0D: Receiver Control Register 1
    0x00_y, // Register 0E: Receiver Control Register 2
    0x22_y, // Register 0F: Receiver PLL1 Configuration Register 1
    0x00_y, // Register 10: Receiver PLL1 Configuration Register 2
    0x00_y, // Register 11: Receiver PLL1 Configuration Register 3
    0x00_y, // Register 12: Non-PCM Audio Detection Status Register (Read-Only)
    0x00_y, // Register 13: Receiver Status Register 1 (Read-Only)
    0x00_y, // Register 14: Receiver Status Register 2 (Read-Only)
    0x00_y, // Register 15: Receiver Status Register 3 (Read-Only)
    0x01_y, // Register 16: Receiver Interrupt Mask Register 1
    0x00_y, // Register 17: Receiver Interrupt Mask Register 2
    0x02_y, // Register 18: Receiver Interrupt Mode Register 1
    0x00_y, // Register 19: Receiver Interrupt Mode Register 2
    0x00_y, // Register 1A: Receiver Interrupt Mode Register 3
    0x01_y, // Register 1B: General-Purpose Output 1 (GPO1) Control Register
    0x00_y, // Register 1C: General-Purpose Output 2 (GPO2) Control Register
    0x0E_y, // Register 1D: General-Purpose Output 3 (GPO3) Control Register
    0x09_y, // Register 1E: General-Purpose Output 4 (GPO4) Control Register
    0x00_y, // Register 1F: Q-Channel Sub-Code Data Register 1 (Read-Only), Bits[7:0], Control and Address
    0x00_y, // Register 20: Q-Channel Sub-Code Data Register 2 (Read-Only), Bits[15:8], Track
    0x00_y, // Register 21: Q-Channel Sub-Code Data Register 3 (Read-Only), Bits[23:16], Index
    0x00_y, // Register 22: Q-Channel Sub-Code Data Register 4 (Read-Only), Bits[31:24], Minutes
    0x00_y, // Register 23: Q-Channel Sub-Code Data Register 5 (Read-Only), Bits[39:32], Seconds
    0x00_y, // Register 24: Q-Channel Sub-Code Data Register 6 (Read-Only), Bits[47:40], Frame
    0x00_y, // Register 25: Q-Channel Sub-Code Data Register 7 (Read-Only), Bits[55:48], Zero
    0x00_y, // Register 26: Q-Channel Sub-Code Data Register 8 (Read-Only), Bits[63:56], AMIN
    0x00_y, // Register 27: Q-Channel Sub-Code Data Register 9 (Read-Only), Bits[71:64], ASEC
    0x00_y, // Register 28: Q-Channel Sub-Code Data Register 10 (Read-Only), Bits[79:72], AFRAME
    0x00_y, // Register 29: Burst Preamble PC High-Byte Status Register (Read-Only)
    0x00_y, // Register 2A: Burst Preamble PC Low-Byte Status Register (Read-Only)
    0x00_y, // Register 2B: Burst Preamble PD High-Byte Status Register (Read-Only)
    0x00_y, // Register 2C: Burst Preamble PD Low-Byte Status Register (Read-Only)
    0x02_y, // Register 2D: SRC Control Register 1
    0x00_y, // Register 2E: SRC Control Register 2
    0x00_y, // Register 2F: SRC Control Register 3
    0x00_y, // Register 30: SRC Control Register 4
    0x00_y, // Register 31: SRC Control Register 5
    0x00_y, // Register 32: SRC Ratio Readback Register (Read-Only)
    0x00_y, // Register 33: SRC Ratio Readback Register (Read-Only)
};

static lpc865::Ftm::Parameters const ftm0par{ .ps=3, .clks=1, .mod=0xFFFF
    , .ch = {
        { .mode=::Ftm::capturePos },    // BLS time stamping
        {},                             // unused    
        { .mode=::Ftm::captureNeg },    // INTA time stamping
        { .mode=::Ftm::captureNeg },    // INTB time stamping
        { .mode=::Ftm::captureNeg },    // INTC time stamping
        { .mode=::Ftm::captureNeg }     // INTD time stamping
    }
};
static lpc865::Ftm::Parameters const ftm1par{ .ps=1, .clks=1, .mod=39999
    , .ch = {
        { .mode=::Ftm::pwmNeg, .inv=1 },
        { .mode=::Ftm::pwmNeg, .inv=1 },
        { .mode=::Ftm::pwmNeg, .inv=1 },
        { .mode=::Ftm::pwmNeg, .inv=1 },
    }
};

static Channel::Integration const i_channel[] = {
    { .in={ .addr = 0, .cpm = 0, .src_present=1 }, .irq=0, .tch=2, .rch=0, .init=srcInitData0 },
    { .in={ .addr = 1, .cpm = 0, .src_present=1 }, .irq=1, .tch=3, .rch=0, .init=srcInitData },
    { .in={ .addr = 2, .cpm = 0, .src_present=1 }, .irq=2, .tch=4, .rch=0, .init=srcInitData },
    { .in={ .addr = 3, .cpm = 0, .src_present=1 }, .irq=3, .tch=5, .rch=0, .init=srcInitData }
};

alignas(512) static std::array<Dma::Descriptor, i_DMA0.max_channel+1> dma_descs;

static lpc865::Dma::Parameters const p_dma = {
    .descs = dma_descs.data()
};

static clocktree::ClockTree<Clocks> clktree;
static Dma dma{ i_DMA0, p_dma };            // DMA controller driver
static Usart usart0{ i_USART0 };            // Host communication USART
static Usart usart1{ i_USART1 };            // Console mode receive USART (RX only)
static Usart usart2{ i_USART2 };            // Mode 3 remote control USART (TX only)
static Pint pint{ i_PINT };                 // Pin interrupt driver
static Ftm ftm0{ i_FTM0, ftm0par };         // Wordclock phase measurements
static Ftm ftm1{ i_FTM1, ftm1par };         // Mode 2 remote control pulse generation
static Wkt wkt{ i_WKT, {1, 0} };
static Spi spi0{ i_SPI0, &dma };            // SRC4392 control communication
static SpiQueue spique{ spi0 };             // Handler queue for SPI0
static Spi spi1{ i_SPI1, nullptr };         // Wordclock generation
static Channel chan[4] = {
    { i_channel[0], spique, ftm0, pint },
    { i_channel[1], spique, ftm0, pint },
    { i_channel[2], spique, ftm0, pint },
    { i_channel[3], spique, ftm0, pint }
};
static Clkmgr clkmgr{pint, chan, 4};

// Operational parameters for target mode I2C0
static I2cTarget::Parameters const p_I2C0 = {
    .addr0 = 0x70,
    .dis1 = 1,
    .dis2 = 1,
    .dis3 = 1,
    .qmode = 1,
    .qual0 = 0x73,
    .callbacks = { &chan[0], &chan[1], &chan[2], &chan[3] }
};

static I2cTarget i2c0{ i_I2C0, p_I2C0 };    // Host communication in target mode

void print(std::string_view buf) {
    do buf.remove_prefix(usart0.send(buf.data(), buf.size()));
    while (!buf.empty());
}

void setActivityLED(bool act) {
    i_GPIO.registers->B[1].B_[7].set(act);
}

int main() {
    i_GPIO.registers->DIRSET[1].set(1 << 7);

    clktree.register_fields[1].set(static_cast<Clocks*>(&clktree), 60000000);

    print("AES42HAT\n");

    ChannelManagement mgmt{chan};
    mgmt.post();

    Handler::run();

    return 0;
}

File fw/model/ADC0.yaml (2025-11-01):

# Created from LPC865.svd

name: ADC0
description: LPC84x 12-bit ADC controller (ADC)
groupName: ADC
registers:
  - name: CTRL
    description: ADC Control register. Contains the clock divide value, resolution
      selection, sampling time selection, and mode controls.
    addressOffset: 0
    size: 32
    access: read-write
    resetValue: 0
    resetMask: 1073743359
    fields:
      - name: CLKDIV
        description: In synchronous mode only, the system clock is divided by this
          value plus one to produce the clock for the ADC converter, which should
          be less than or equal to 72 MHz. Typically, software should program the
          smallest value in this field that yields this maximum clock rate or slightly
          less, but in certain cases (such as a high-impedance analog source) a slower
          clock may be desirable. This field is ignored in the asynchronous operating
          mode.
        bitOffset: 0
        bitWidth: 8
        access: read-write
      - name: ASYNMODE
        description: Select clock mode.
        bitOffset: 8
        bitWidth: 1
        access: read-write
        enumeratedValues:
          - name: SYNCHRONOUS_MODE
            description: Synchronous mode. The ADC clock is derived from the system
              clock based on the divide value selected in the CLKDIV field. The ADC
              clock will be started in a controlled fashion in response to a trigger
              to eliminate any uncertainty in the launching of an ADC conversion in
              response to any synchronous (on-chip) trigger. In Synchronous mode with
              the SYNCBYPASS bit (in a sequence control register) set, sampling of
              the ADC input and start of conversion will initiate 2 system clocks
              after the leading edge of a (synchronous) trigger pulse.
            value: 0
          - name: ASYNCHRONOUS_MODE
            description: Asynchronous mode. The ADC clock is based on the output of
              the ADC clock divider ADCCLKSEL in the SYSCON block.
            value: 1
      - name: LPWRMODE
        description: The low-power ADC mode
        bitOffset: 10
        bitWidth: 1
        access: read-write
        enumeratedValues:
          - name: LPWRMODE_0
            description: The low-power ADC mode is disabled. The analog circuitry
              remains activated even when no conversions are requested.
            value: 0
          - name: LPWRMODE_1
            description: 'The low-power ADC mode is enabled. The analog circuitry
              is automatically powered-down when no conversions are taking place.
              When any (hardware or software) triggering event is detected, the analog
              circuitry is enabled. After the required start-up time, the requested
              conversion will be launched. Once the conversion completes, the analog-circuitry
              will again be powered-down provided no further conversions are pending.
              Using this mode can save an appreciable amount of current (approximately
              2.5 mA) when conversions are required relatively infrequently. The penalty
              for using this mode is an approximately FIFTEEN ADC CLOCK delay (30
              clocks in 10-bit mode), based on the frequency specified in the CLKDIV
              field, from the time the trigger event occurs until sampling of the
              A/D input commences. Note: This mode will NOT power-up the A/D if the
              ADC_ENA bit is low.'
            value: 1
      - name: CALMODE
        description: "Writing a '1' to this bit will initiate a sef-calibration cycle.
          This bit will be automatically cleared by hardware after the calibration
          cycle is complete. Note: Other bits of this register may be written to concurrently
          with setting this bit, however once this bit has been set no further writes
          to this register are permitted unitl the full calibration cycle has ended."
        bitOffset: 30
        bitWidth: 1
        access: read-write
  - dim: 2
    dimIncrement: 4
    dimIndex: A,B
    name: SEQ_CTRL%s
    description: 'ADC Conversion Sequence-n control register: Controls triggering
      and channel selection for conversion sequence-n. Also specifies interrupt mode
      for sequence-n.'
    addressOffset: 8
    size: 32
    access: read-write
    resetValue: 0
    resetMask: 4228907007
    fields:
      - name: CHANNELS
        description: Selects which one or more of the ADC channels will be sampled
          and converted when this sequence is launched. A 1 in any bit of this field
          will cause the corresponding channel to be included in the conversion sequence,
          where bit 0 corresponds to channel 0, bit 1 to channel 1 and so forth. When
          this conversion sequence is triggered, either by a hardware trigger or via
          software command, ADC conversions will be performed on each enabled channel,
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

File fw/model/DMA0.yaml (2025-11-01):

# Created from LPC865.svd

name: DMA0
description: LPC84x DMA controller
groupName: DMA
registers:
  - name: CTRL
    description: DMA control.
    addressOffset: 0
    size: 32
    access: read-write
    resetValue: 0
    resetMask: 1
    fields:
      - name: ENABLE
        description: DMA controller master enable.
        bitOffset: 0
        bitWidth: 1
        access: read-write
        enumeratedValues:
          - name: DISABLED
            description: Disabled. The DMA controller is disabled. This clears any
              triggers that were asserted at the point when disabled, but does not
              prevent re-triggering when the DMA controller is re-enabled.
            value: 0
          - name: ENABLED
            description: Enabled. The DMA controller is enabled.
            value: 1
  - name: INTSTAT
    description: Interrupt status.
    addressOffset: 4
    size: 32
    access: read-only
    resetValue: 0
    resetMask: 6
    fields:
      - name: ACTIVEINT
        description: Summarizes whether any enabled interrupts (other than error interrupts)
          are pending.
        bitOffset: 1
        bitWidth: 1
        access: read-only
        enumeratedValues:
          - name: NOT_PENDING
            description: Not pending. No enabled interrupts are pending.
            value: 0
          - name: PENDING
            description: Pending. At least one enabled interrupt is pending.
            value: 1
      - name: ACTIVEERRINT
        description: Summarizes whether any error interrupts are pending.
        bitOffset: 2
        bitWidth: 1
        access: read-only
        enumeratedValues:
          - name: NOT_PENDING
            description: Not pending. No error interrupts are pending.
            value: 0
          - name: PENDING
            description: Pending. At least one error interrupt is pending.
            value: 1
  - name: SRAMBASE
    description: SRAM address of the channel configuration table.
    addressOffset: 8
    size: 32
    access: read-write
    resetValue: 0
    resetMask: 4294966784
    fields:
      - name: OFFSET
        description: Address bits 31:9 of the beginning of the DMA descriptor table.
          For 18 channels, the table must begin on a 512 byte boundary.
        bitOffset: 9
        bitWidth: 23
        access: read-write
  - name: ENABLESET0
    description: Channel Enable read and Set for all DMA channels.
    addressOffset: 32
    size: 32
    access: read-write
    resetValue: 0
    resetMask: 67108863
    fields:
      - name: ENA
        description: Enable for DMA channels. Bit n enables or disables DMA channel
          n. The number of bits = number of DMA channels in this device. Other bits
          are reserved. 0 = disabled. 1 = enabled.
        bitOffset: 0
        bitWidth: 25
        access: read-write
  - name: ENABLECLR0
    description: Channel Enable Clear for all DMA channels.
    addressOffset: 40
    size: 32
    access: write-only
    resetValue: 0
    resetMask: 0
    fields:
      - name: CLR
        description: Writing ones to this register clears the corresponding bits in
          ENABLESET0. Bit n clears the channel enable bit n. The number of bits =
          number of DMA channels in this device. Other bits are reserved.
        bitOffset: 0
        bitWidth: 25
        access: write-only
  - name: ACTIVE0
    description: Channel Active status for all DMA channels.
    addressOffset: 48
    size: 32
    access: read-only
    resetValue: 0
    resetMask: 4294967295
    fields:
      - name: ACT
        description: Active flag for DMA channel n. Bit n corresponds to DMA channel
          n. The number of bits = number of DMA channels in this device. Other bits
          are reserved. 0 = not active. 1 = active.
        bitOffset: 0
        bitWidth: 25
        access: read-only
  - name: BUSY0
    description: Channel Busy status for all DMA channels.
    addressOffset: 56
    size: 32
    access: read-only
    resetValue: 0
    resetMask: 4294967295
    fields:
      - name: BSY
        description: Busy flag for DMA channel n. Bit n corresponds to DMA channel
          n. The number of bits = number of DMA channels in this device. Other bits
          are reserved. 0 = not busy. 1 = busy.
        bitOffset: 0
        bitWidth: 25
        access: read-only
  - name: ERRINT0
    description: Error Interrupt status for all DMA channels.
    addressOffset: 64
    size: 32
    access: read-write
    resetValue: 0
    resetMask: 4294967295
    fields:
      - name: ERR
        description: Error Interrupt flag for DMA channel n. Bit n corresponds to
          DMA channel n. The number of bits = number of DMA channels in this device.
          Other bits are reserved. 0 = error interrupt is not active. 1 = error interrupt
          is active.
        bitOffset: 0
        bitWidth: 25
        access: read-write
  - name: INTENSET0
    description: Interrupt Enable read and Set for all DMA channels.
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

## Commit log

2024-05-21 First design import
    [AES42HAT.kicad_pcb, AES42HAT.kicad_sch, Wuerth_74930030.stp]
2024-11-03 Describe pin functions, and change controller pin assignments for better timer usage.
    [AES42HAT.kicad_pcb, AES42HAT.kicad_sch]
2025-04-10 Layout added.
    [AES42HAT.kicad_pcb, AES42HAT.kicad_sch]
2025-04-11 PCB update.
    [AES42HAT.csv, AES42HAT.kicad_pcb, AES42HAT.kicad_sch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]
2025-05-29 Add a couple of blocking caps, and mark connectors as don't populate.
    [AES42HAT.kicad_sch]
2025-05-29 U3 als unbestückt markiert
    [AES42HAT.kicad_sch]
2025-07-04 Layout update.
    [AES42HAT-B_Cu.gbl, AES42HAT-B_Fab.gbr, AES42HAT-B_Mask.gbs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]
2025-07-04 Move hardware into its own folder
    [AES42HAT-B_Cu.gbl, AES42HAT-B_Fab.gbr, AES42HAT-B_Mask.gbs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]
2025-09-07 I2C update
2025-10-26 Update to KiCad 9
    [AES42HAT.kicad_pcb]
2025-10-26 Add first attempt at a device tree overlay source file
2025-10-27 device tree makefile
2025-11-10 Add a few drivers
2025-11-11 Back to 7.5 MBit/s on SPI
2025-11-11 FTM driver progress.
2025-11-19 Add a handler class, and add some more drivers
2025-11-20 Add interrupt code
2025-11-20 Add WKT driver
2025-11-20 Handle interrupt vector table in NVIC driver
2025-11-20 Use NVIC driver in I2C driver
2025-11-20 Interrupt-driven, WKT controlled blinky
2025-11-23 Slow down SPI
2025-11-23 I2C fixes
2025-11-23 Fix some clocking, and provide global print()
    [main.cpp, startup.cpp]
2025-11-25 Set up pin interrupts
2025-11-25 Fix interrupt initialization
2025-11-25 FTM driver refactored
2025-11-25 Implement pin interrupt driver
2025-11-27 Fix naming of generated headers
    [main.cpp, startup.cpp]
2025-12-05 Introduce DMA for SPI comms
2026-03-03 Prepare driver files for non-inline peripheral namespaces
    Add explicit using-namespace declarations to each driver file
    for the peripheral types they use. This prepares for a generator
    change where the peripheral-level namespace becomes non-inline
    (and drops the trailing underscore), avoiding ambiguity with
    identically-named inline namespaces inside SYSCON.
    Includes a task description file for the generator project.
    [ftm_drv.cpp, i2c_tgt_drv.cpp, spi_drv.cpp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]
2026-04-05 Convert handler, nvic_drv, utility, stackring, and queuering to C++20 modules
    Phase 1 of the C++20 modules conversion: replace these internal headers with
    module interface units (.cppm), update all consumers to use import declarations,
    and register the new module sources in CMakeLists.txt.
    [ftm_drv.cpp]
2026-04-05 Convert remaining driver headers to C++20 modules
    Phase 2: convert dma_drv, ftm_drv, i2c_tgt_drv, pint_drv, spi_drv,
    spi_queue, src4392_drv, usart_drv, and wkt_drv from headers to module
    interface units (.cppm), and update all consumers accordingly.
